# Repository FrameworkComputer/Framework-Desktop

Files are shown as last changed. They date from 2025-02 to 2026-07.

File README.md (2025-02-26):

# Framework-Desktop
Documentation for the Mainboard and printable mechanical parts in the Framework Desktop.

Framework-Desktop-Teardown-2025

## License

Framework Desktop © 2025 by Framework Computer Inc is licensed under CC BY 4.0.
To view a copy of this license, visit https://creativecommons.org/licenses/by/4.0/

## Mainboard

Framework Desktop uses a standard size Mini-ITX Mainboard with standard ATX connectors.

## Case

CAD to enable creation of custom handles and top covers.

## Tiles

CAD to enable creation of custom front tiles.

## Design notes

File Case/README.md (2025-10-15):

# Case

## Case

CAD for the overall case structure.

## Left Panel

CAD for the left panel.

## Top Cover

CAD for the Top Cover part of the Framework Desktop to design alternative versions.

## Handle

OpenSCAD CAD and STL to 3D print a carrying handle for Framework Desktop.

Needs 2x M6 x 12mm (up to 13mm or so) bolts or thumbscrews to attach it.

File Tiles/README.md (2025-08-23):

# Front Cover and Tiles

## License

Front Cover and Tiles © 2025 by Framework Computer Inc is licensed under CC BY 4.0.
To view a copy of this license, visit http://creativecommons.org/licenses/by/4.0/

## Designs

### Front Cover

[fw_desktop_front_cover.stl](fw_desktop_front_cover.stl) is the 3D design file
for the front cover.

The 3D file is mainly intented to help the community develop tiles that are compatible with the official front cover. It does not include magnets or the power button.
If you'd like to attach it to the Framework Desktop you need magnets of size 8.50x5.00x1.10mm. Eight of those are used in the product.

### Tiles

To develop your own tiles we provide 2D and 3D files for the flat printed tiles:

- 2D
    - [FRAMEWORK_DESKTOP_BLANK_TILE.stp](FRAMEWORK_DESKTOP_BLANK_TILE.stp)
- 3D
    - [FRAMEWORK_DESKTOP_BLANK_TILE_V0.pdf](FRAMEWORK_DESKTOP_BLANK_TILE_V0.pdf)
    - [framework_desktop_blank_tile_v0_1.dxf](framework_desktop_blank_tile_v0_1.dxf)
    - [framework_desktop_blank_tile_v0_2.dxf](framework_desktop_blank_tile_v0_2.dxf)
    - [framework_desktop_blank_tile_v0_3.dxf](framework_desktop_blank_tile_v0_3.dxf)

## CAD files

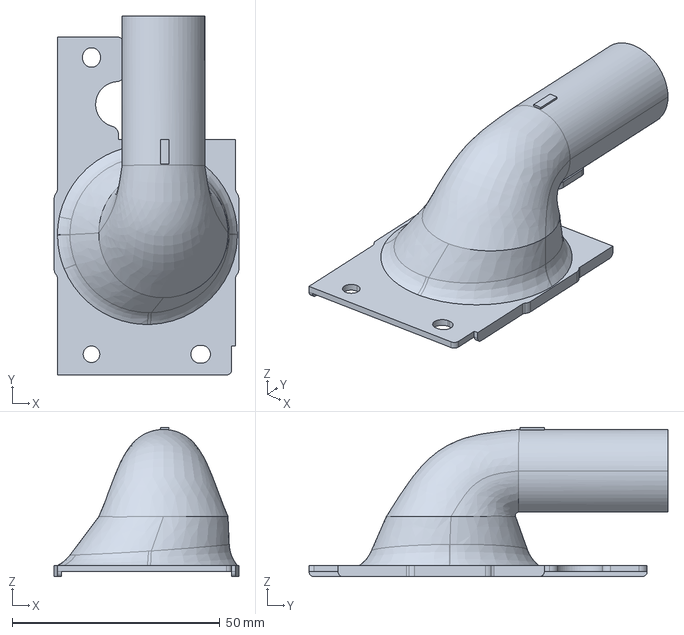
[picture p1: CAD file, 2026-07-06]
Case/framework_desktop_psu_duct.stp
44.5 x 86.5 x 36.0 mm

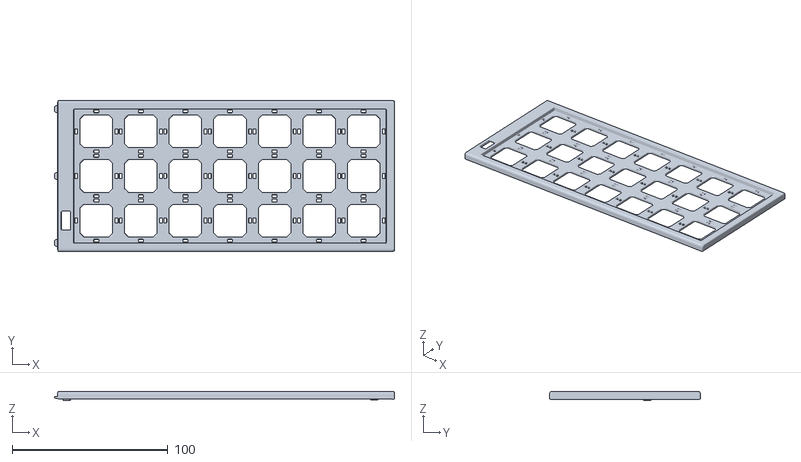
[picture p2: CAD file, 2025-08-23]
Tiles/fw_desktop_front_cover.stl
218.2 x 96.8 x 6.00

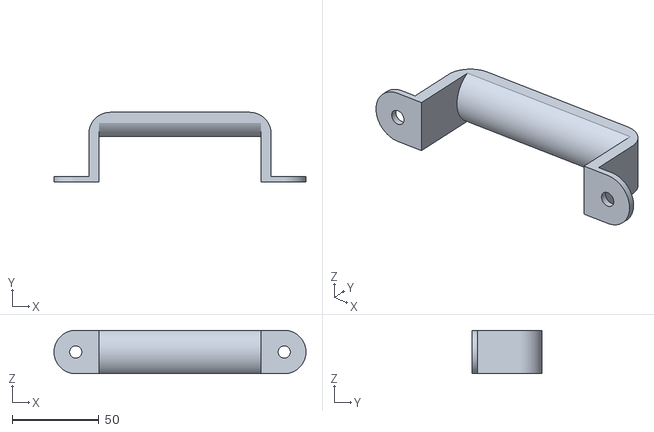
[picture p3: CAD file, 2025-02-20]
Case/handle.stl
145.0 x 40.0 x 25.0

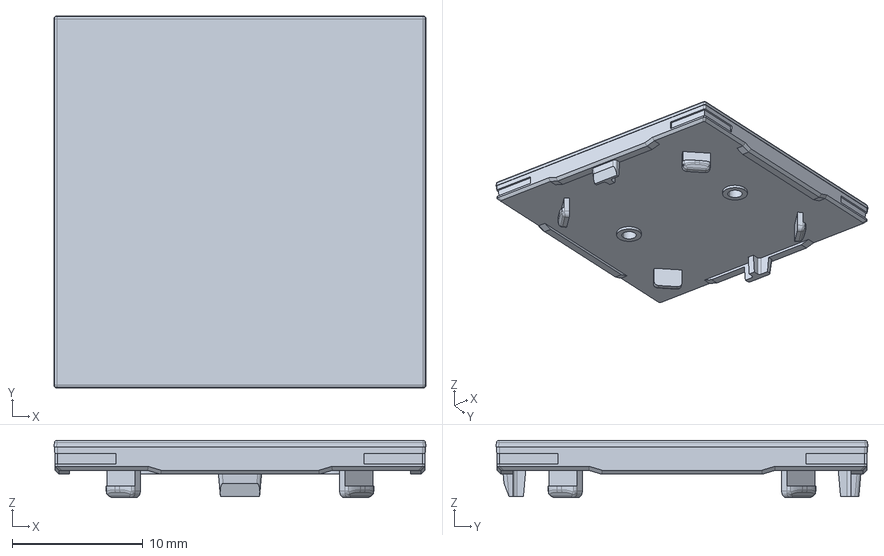
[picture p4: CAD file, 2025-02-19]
Tiles/FRAMEWORK_DESKTOP_BLANK_TILE.stp
28.5 x 28.5 x 4.40 mm

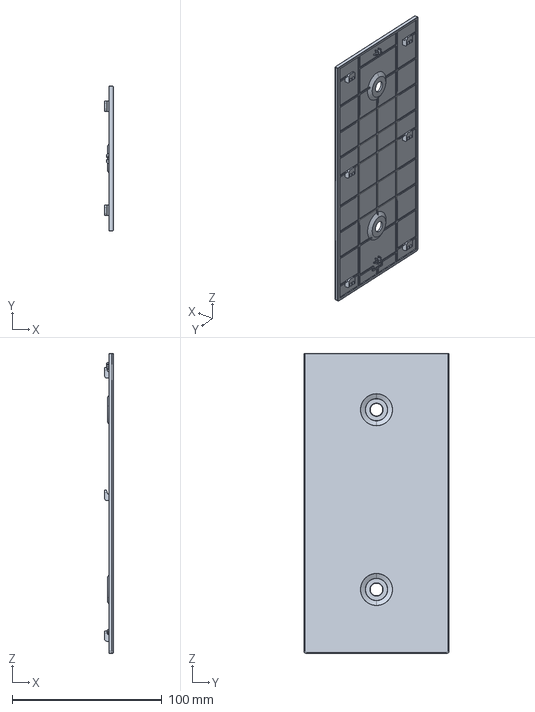
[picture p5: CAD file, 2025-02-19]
Case/FRAMEWORK_DESKTOP_TOP_COVER_V0.stp
5.85 x 96.8 x 200.3 mm

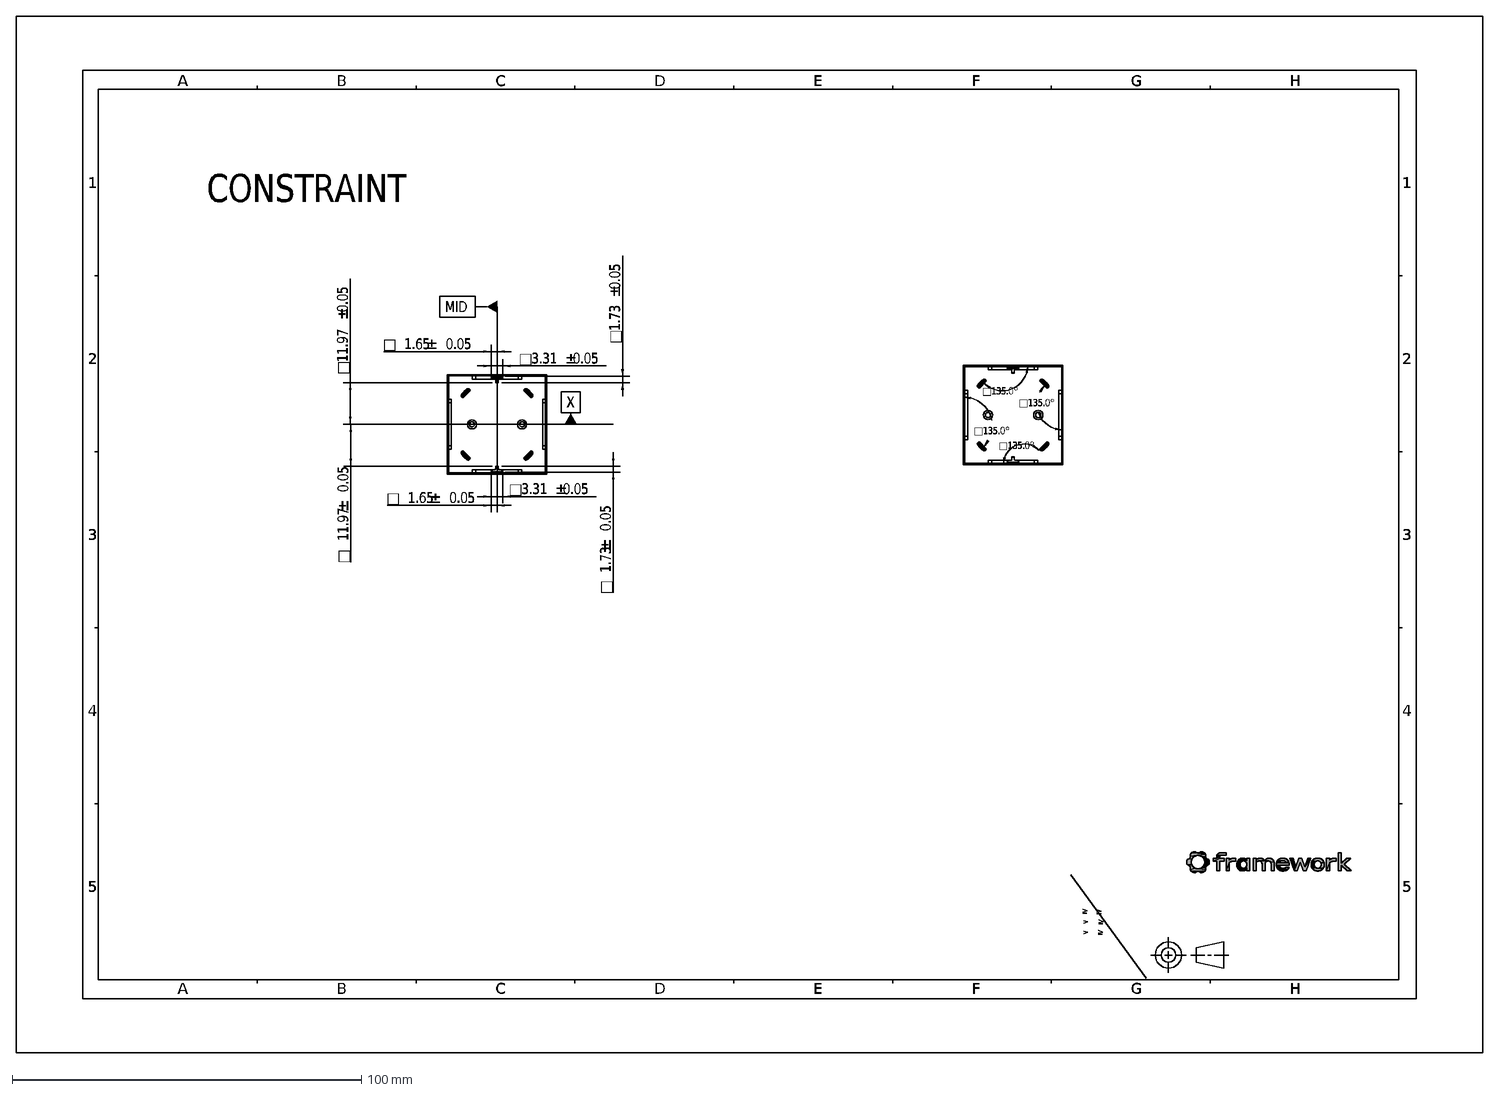
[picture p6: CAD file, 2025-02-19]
Tiles/framework_desktop_blank_tile_v0_3.dxf
A
B
5
4
3
2
1
C
D
E
F
G
H
MID
X
3.31
0.05
1.65
1.73
11.97
CONSTRAINT

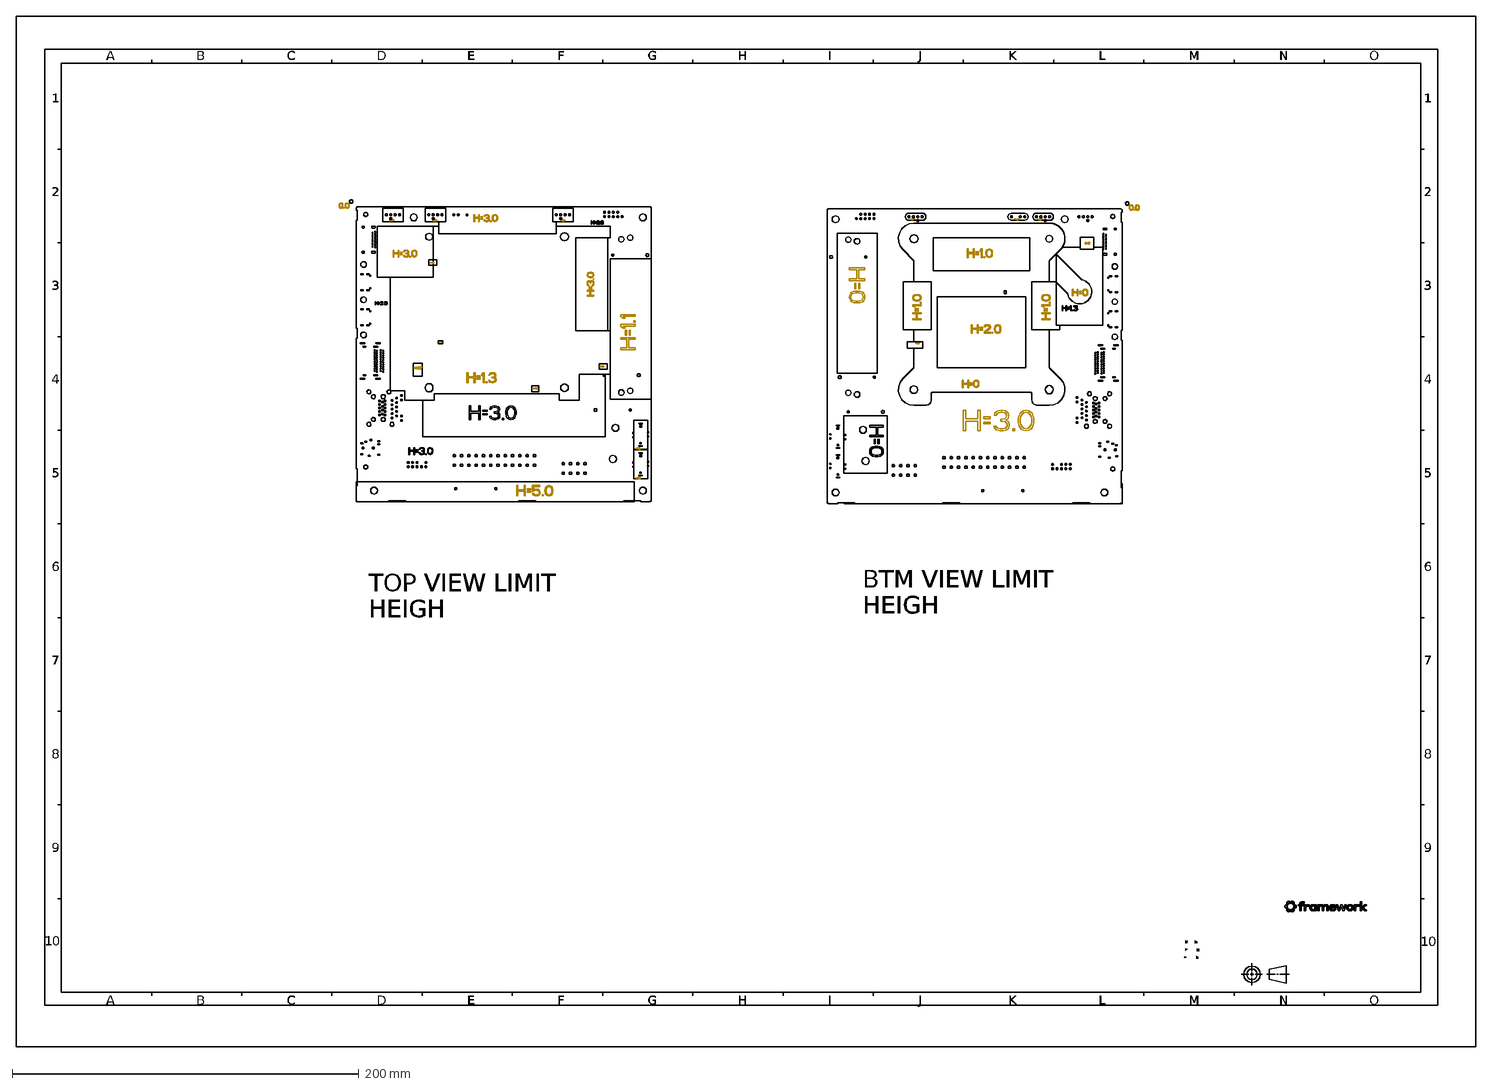
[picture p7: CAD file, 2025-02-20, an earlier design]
Mainboard/framework_desktop_main_pcb_v0_3.dxf
A
10
B
C
9
8
D
E
F
G
6
7
5
4
3
2
1
H
I
J
K
L
M
N
O
TOP VIEW LIMIT HEIGH
BTM VIEW LIMIT HEIGH

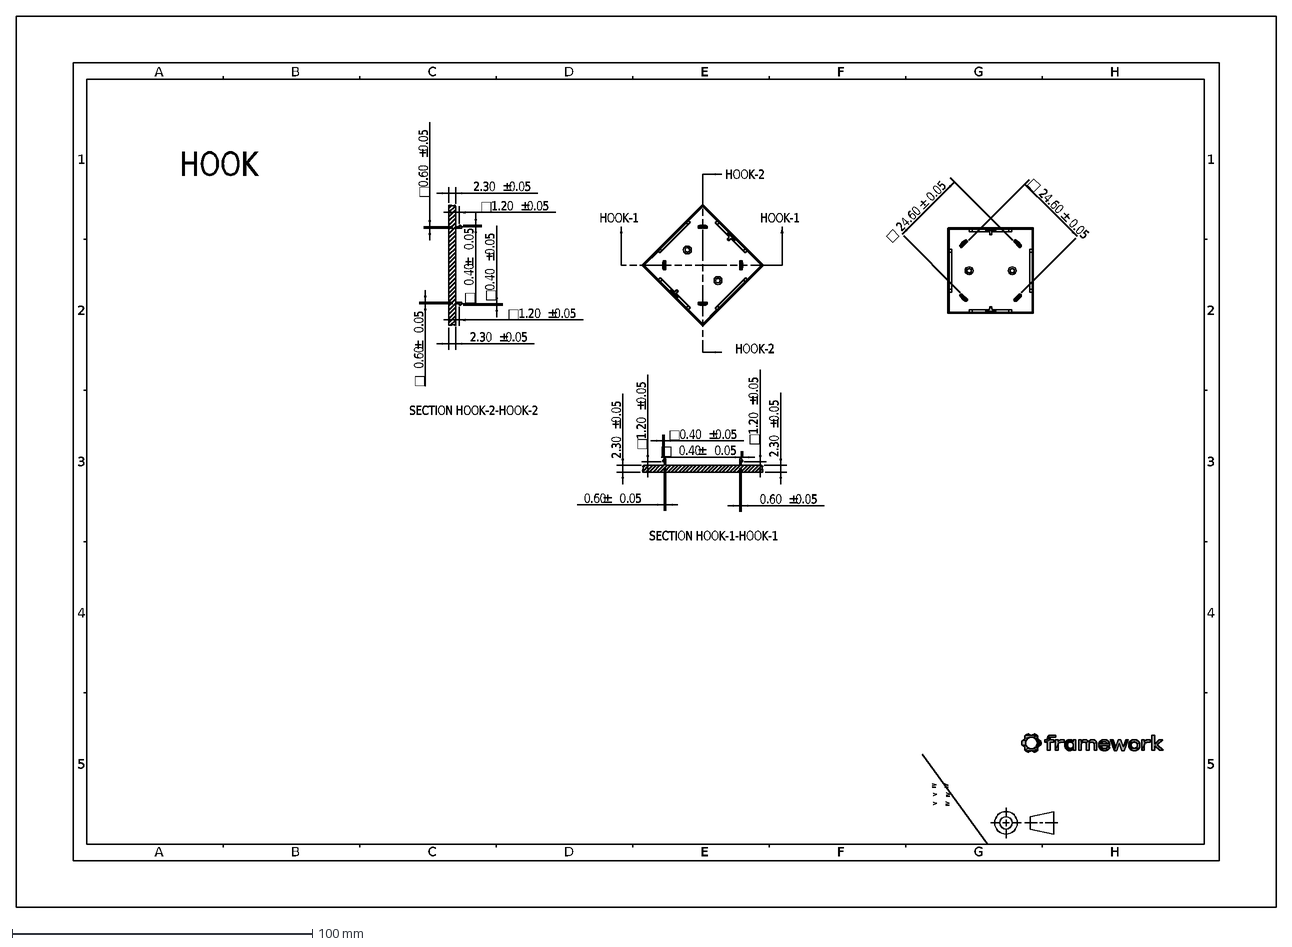
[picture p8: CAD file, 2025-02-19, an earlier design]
Tiles/framework_desktop_blank_tile_v0_2.dxf
A
B
5
4
3
2
1
C
D
E
F
G
H
HOOK-1
HOOK-2
1.20
0.05
0.40
2.30
0.60
24.60
HOOK
SECTION HOOK-1-HOOK-1
SECTION HOOK-2-HOOK-2

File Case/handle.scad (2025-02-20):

// Framework Desktop Handle
//  An OpenSCAD implementation of a carrying handle for the Framework Desktop
//
//  Print it laying on its side for layer strength.
//  Needs 2x M6 x 12mm bolts or thumbscrews to attach to the system.
//
// Framework Desktop Handle © 2025 Framework Computer Inc
// is licensed under Attribution 4.0 International. 
// To view a copy of this license, visit http://creativecommons.org/licenses/by/4.0/

include <MCAD/boxes.scad>;

// Matching the bolt spacing on the Top Cover
hole_to_hole = 120;

// Handle height
height = 40;
// Handle width
width = 25;
// Tradeoff between more thumbscrew clearance vs hand space
hole_offset = 15;
thickness = width/2;
// 3mm is enough strength when using typical filament
base_thickness = 3;
r = thickness;
// Bolt hole diameter
m6_r = 6/2 + 0.5;

$fn = 128;

difference() {
    union() {
        intersection() {
            // Rounding the overall shape of the handle by starting with a rounded cube
            translate([hole_offset/2, -r, 0]) roundedCube([hole_to_hole - hole_offset, height + r, width], r, true);
            // Rounding each section of the handle by making each a cylinder
            union() {
                // The two vertical pieces
                translate([hole_offset/2, 0, width]) rotate([-90, 0, 0]) cube([base_thickness*2, width, height]);
                translate([hole_to_hole - hole_offset/2 - base_thickness*2, 0, width]) rotate([-90, 0, 0]) cube([base_thickness*2, width, height]);
                // The horizontal piece
                translate([hole_offset/2, height, width/2]) rotate([0, 90, 0]) cylinder(h = hole_to_hole - hole_offset, r = width/2 + base_thickness/2); 
            }
        }
        
        // The flat parts that the bolts go through
        mount_length = width + hole_offset/2;
        translate([-width/2, 0, width]) rotate([-90, 0, 0]) roundedCube([mount_length, width, base_thickness], width/2, true);
        translate([hole_to_hole - width + (width - hole_offset)/2, 0, width]) rotate([-90, 0, 0]) roundedCube([mount_length, width, base_thickness], width/2, true);
    }
    
    // Cutting out the hand area on the base
    translate([hole_offset/2 + base_thickness*2, 0, 0]) cube([hole_to_hole - hole_offset - base_thickness*4, height - r - base_thickness/2, width]);
    
    // The bolt holes
    translate([0, 0, width/2]) rotate([-90, 0, 0]) cylinder(h = height, r = m6_r);
    translate([hole_to_hole, 0, width/2]) rotate([-90, 0, 0]) cylinder(h = height, r = m6_r);    
}

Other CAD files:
Mainboard/framework_desktop_main_pcb_v0_4.dxf
Case/framework_desktop_topcover_v0_2.dxf
Mainboard/framework_desktop_main_pcb_v0_2.dxf
Tiles/framework_desktop_blank_tile_v0_1.dxf
Case/framework_desktop_topcover_v0_1.dxf

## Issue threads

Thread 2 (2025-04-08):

Add cooler and fan shroud to the 3d model of the motherboard

KonradStuewe, 2025-04-08:
Is there any way that you can publish the 3D model of the cooler and the fan shroud?
I'm trying to make my own case and knowing where exactly the fan sits in relation to the rest of the board, would really help with that.

Djip007, 2025-05-23:
All size is here https://github.com/FrameworkComputer/Framework-Desktop/blob/main/Mainboard/FRAMEWORK_DESKTOP_MAIN_PCB_V0.pdf

but yes not in stl.

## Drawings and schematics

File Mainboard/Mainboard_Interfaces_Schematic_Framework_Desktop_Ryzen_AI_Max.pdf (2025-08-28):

# Block Diagram

# APU

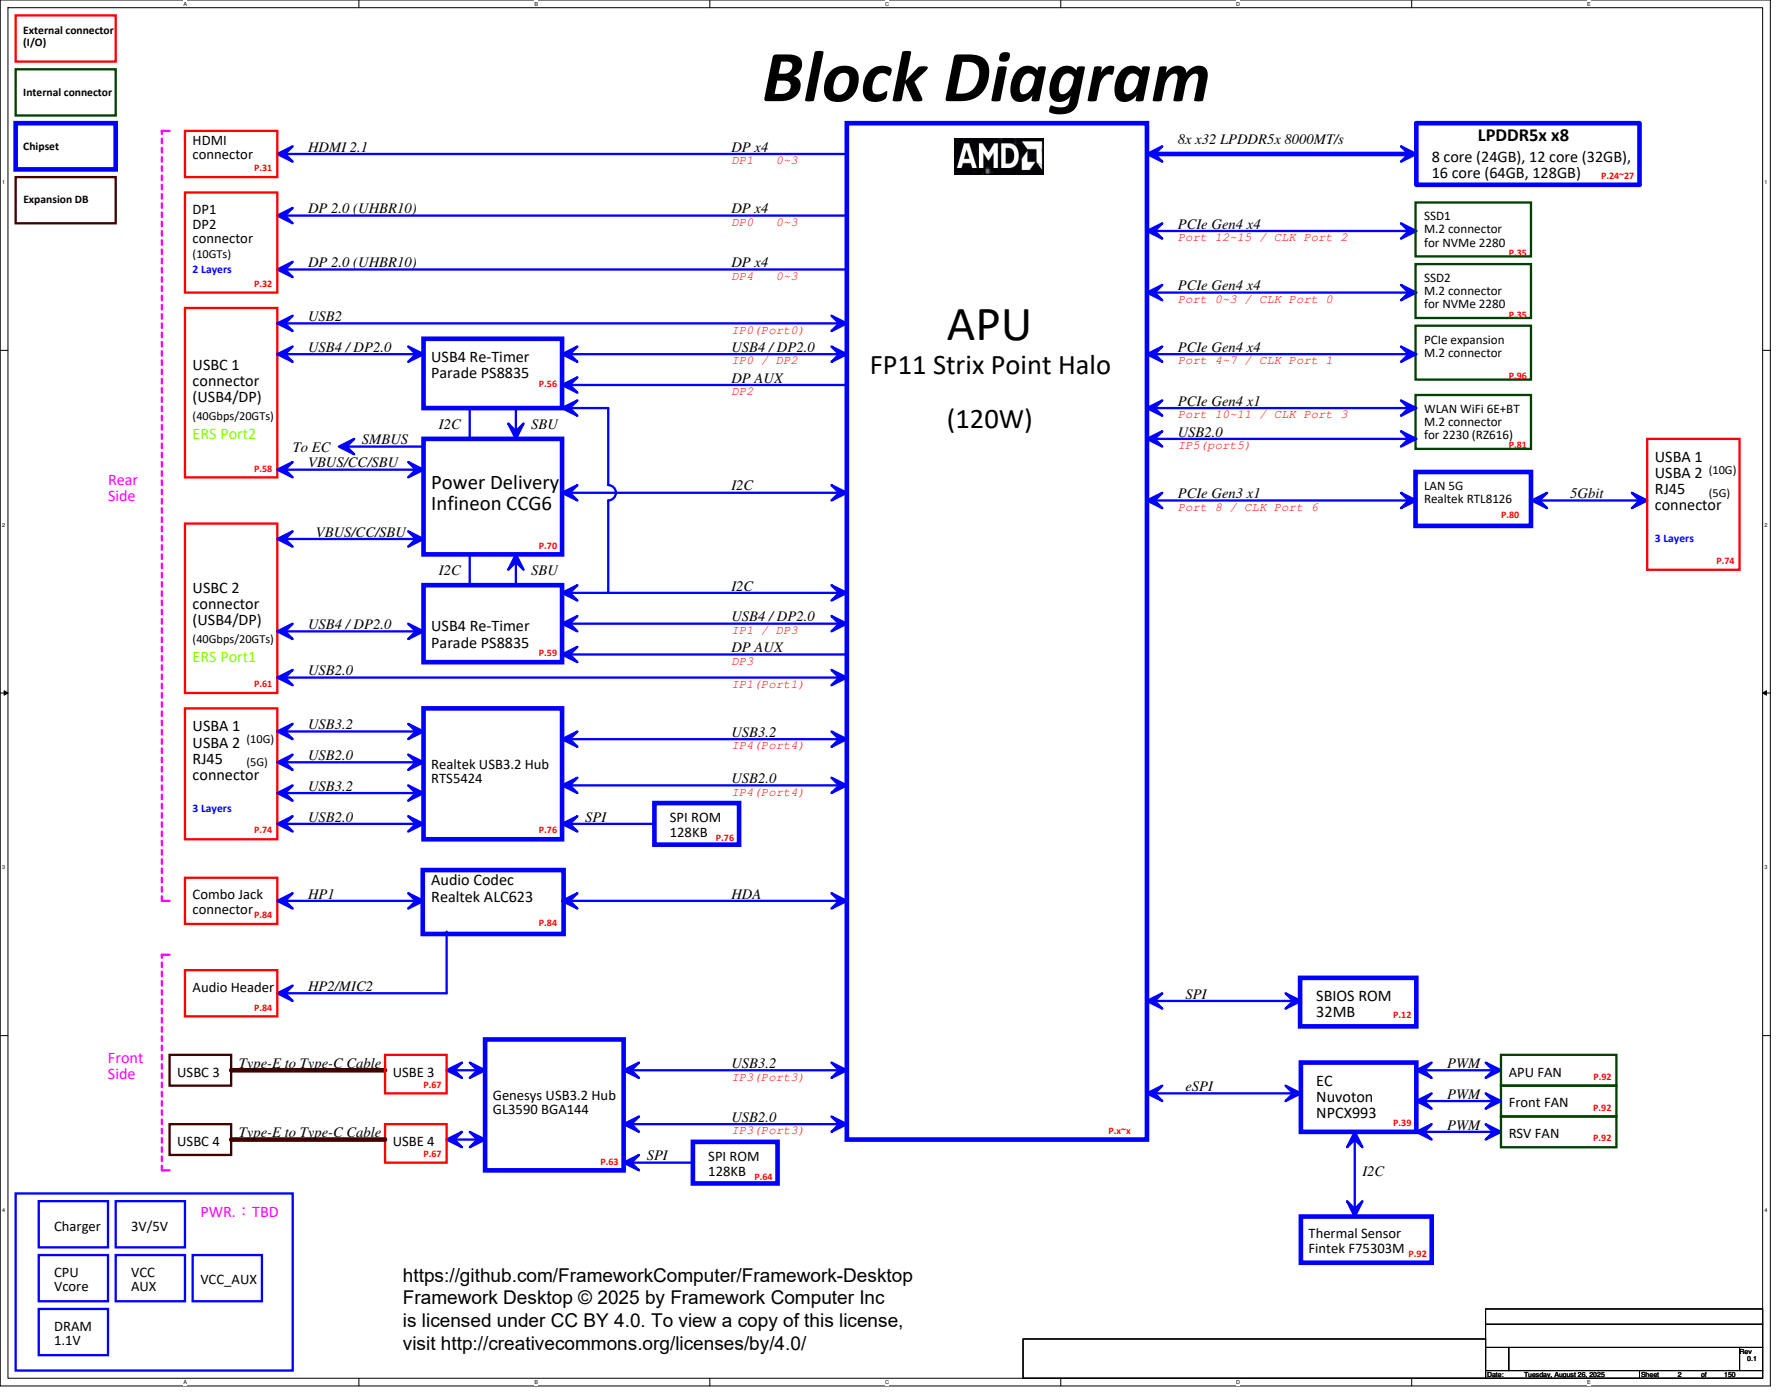
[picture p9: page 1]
SBIOS ROM 32MB; VCC AUX; Charger; CPU; Vcore; VCC_AUX; DRAM 1.1V; USBC 1 connector (USB4/DP); Power Delivery Infineon CCG6; LPDDR5x x8; 8 core (24GB), 12 core (32GB), 16 core (64GB, 128GB); 8x x32 LPDDR5x 8000MT/s; USB4 / DP2.0; HDMI 2.1; HDMI; connector; DP 2.0 (UHBR10); USBC 2 connector (USB4/DP); Internal connector; External connector (I/O); Chipset; IP4(Port4); SSD2 M.2 connector for NVMe 2280; PCIe expansion M.2 connector; SSD1 M.2 connector for NVMe 2280; PCIe Gen3 x1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

PCIe Gen4 x4
Port 12~15 / CLK Port 2

Port 0~3 / CLK Port 0

Port 4~7 / CLK Port 1

FP11 Strix Point Halo

WLAN WiFi 6E+BT
M.2 connector
for 2230 (RZ616)

VBUS/CC/SBU

Port 8 / CLK Port 6

Type-E to Type-C Cable

Front FAN PWM

RSV FAN PWM

https://github.com/FrameworkComputer/Framework-Desktop
Framework Desktop © 2025 by Framework Computer Inc
is licensed under CC BY 4.0. To view a copy of this license,
visit http://creativecommons.org/licenses/by/4.0/

## Main Function:

# S0ix Off

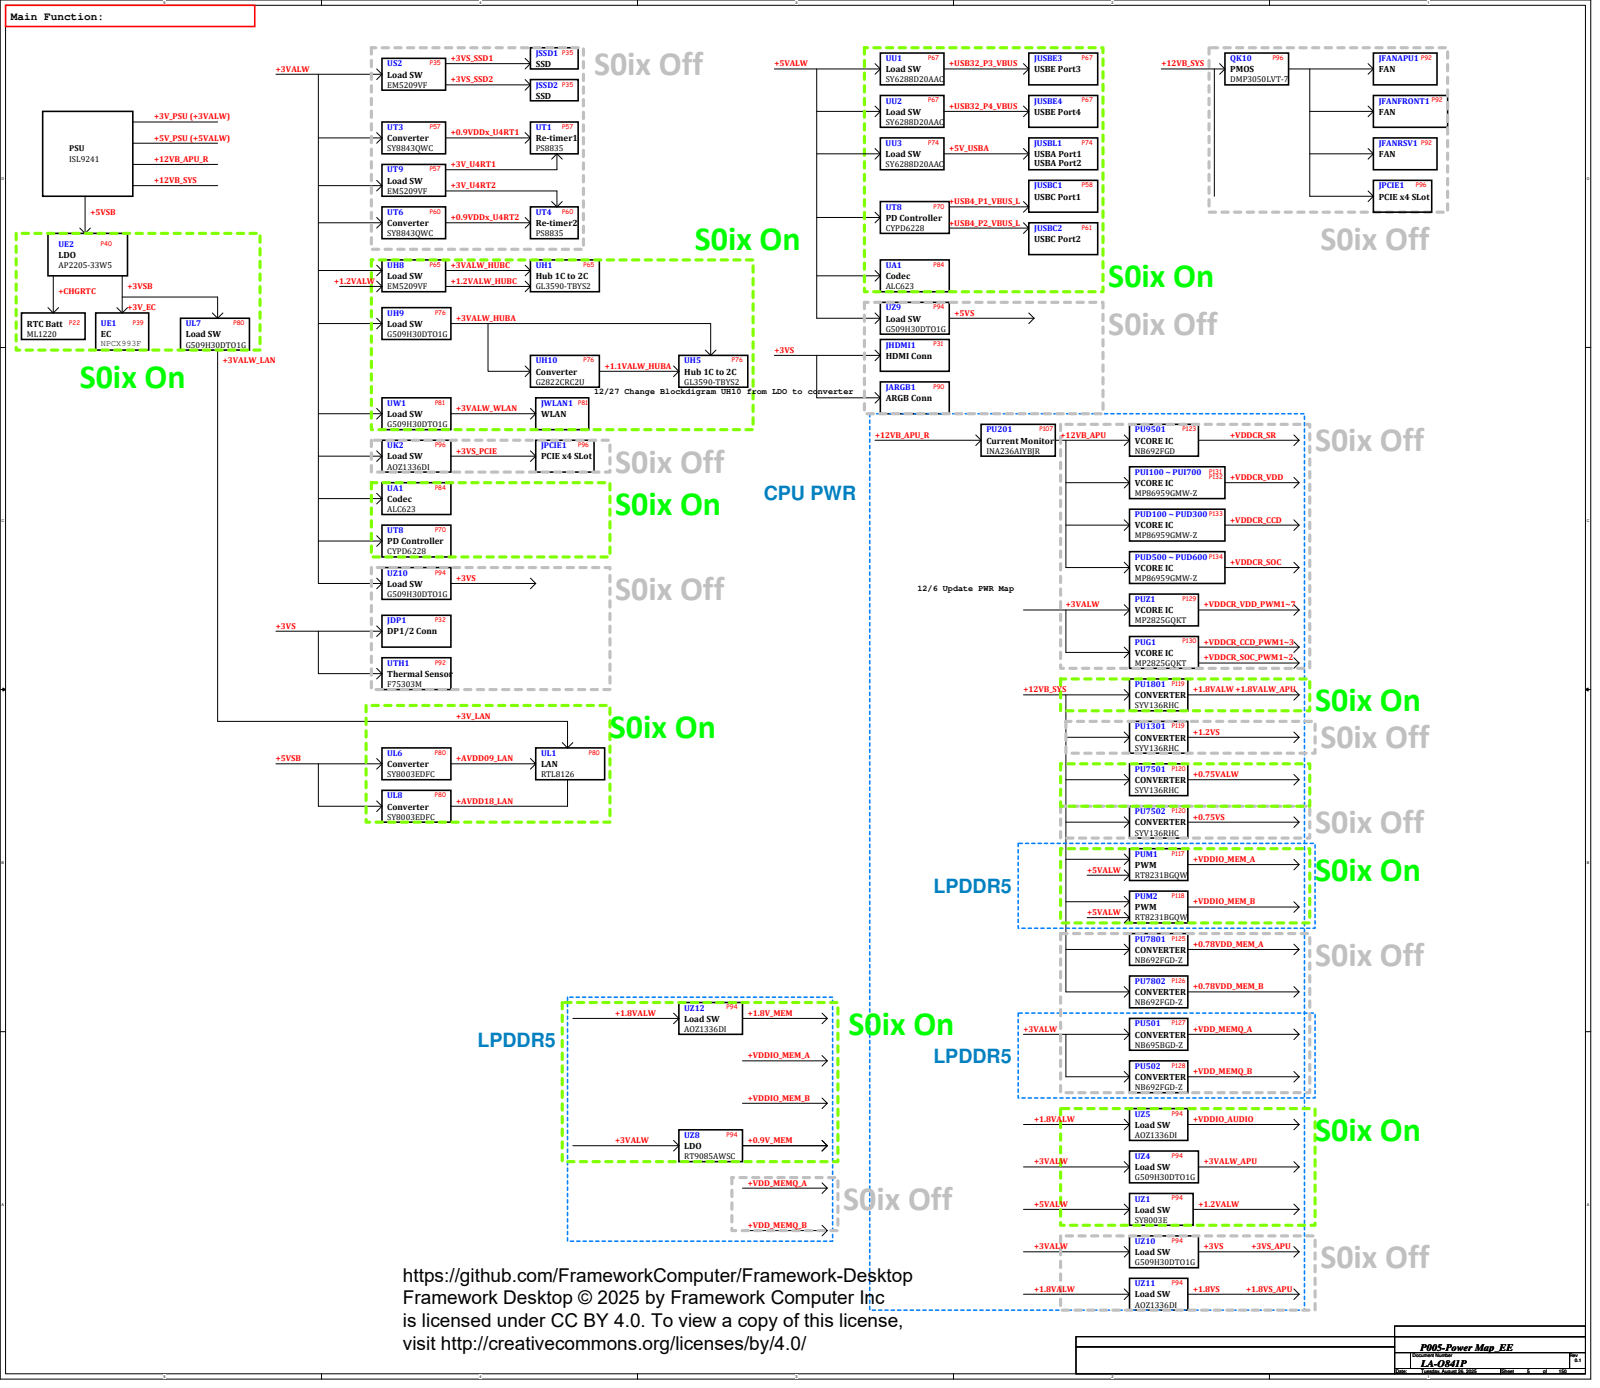
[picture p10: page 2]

12/27 Change Blockdigram UH10 from LDO to converter

https://github.com/FrameworkComputer/Framework-Desktop
Framework Desktop © 2025 by Framework Computer Inc

# HDMI_CEC

## 8/5 change to +3VL_EC

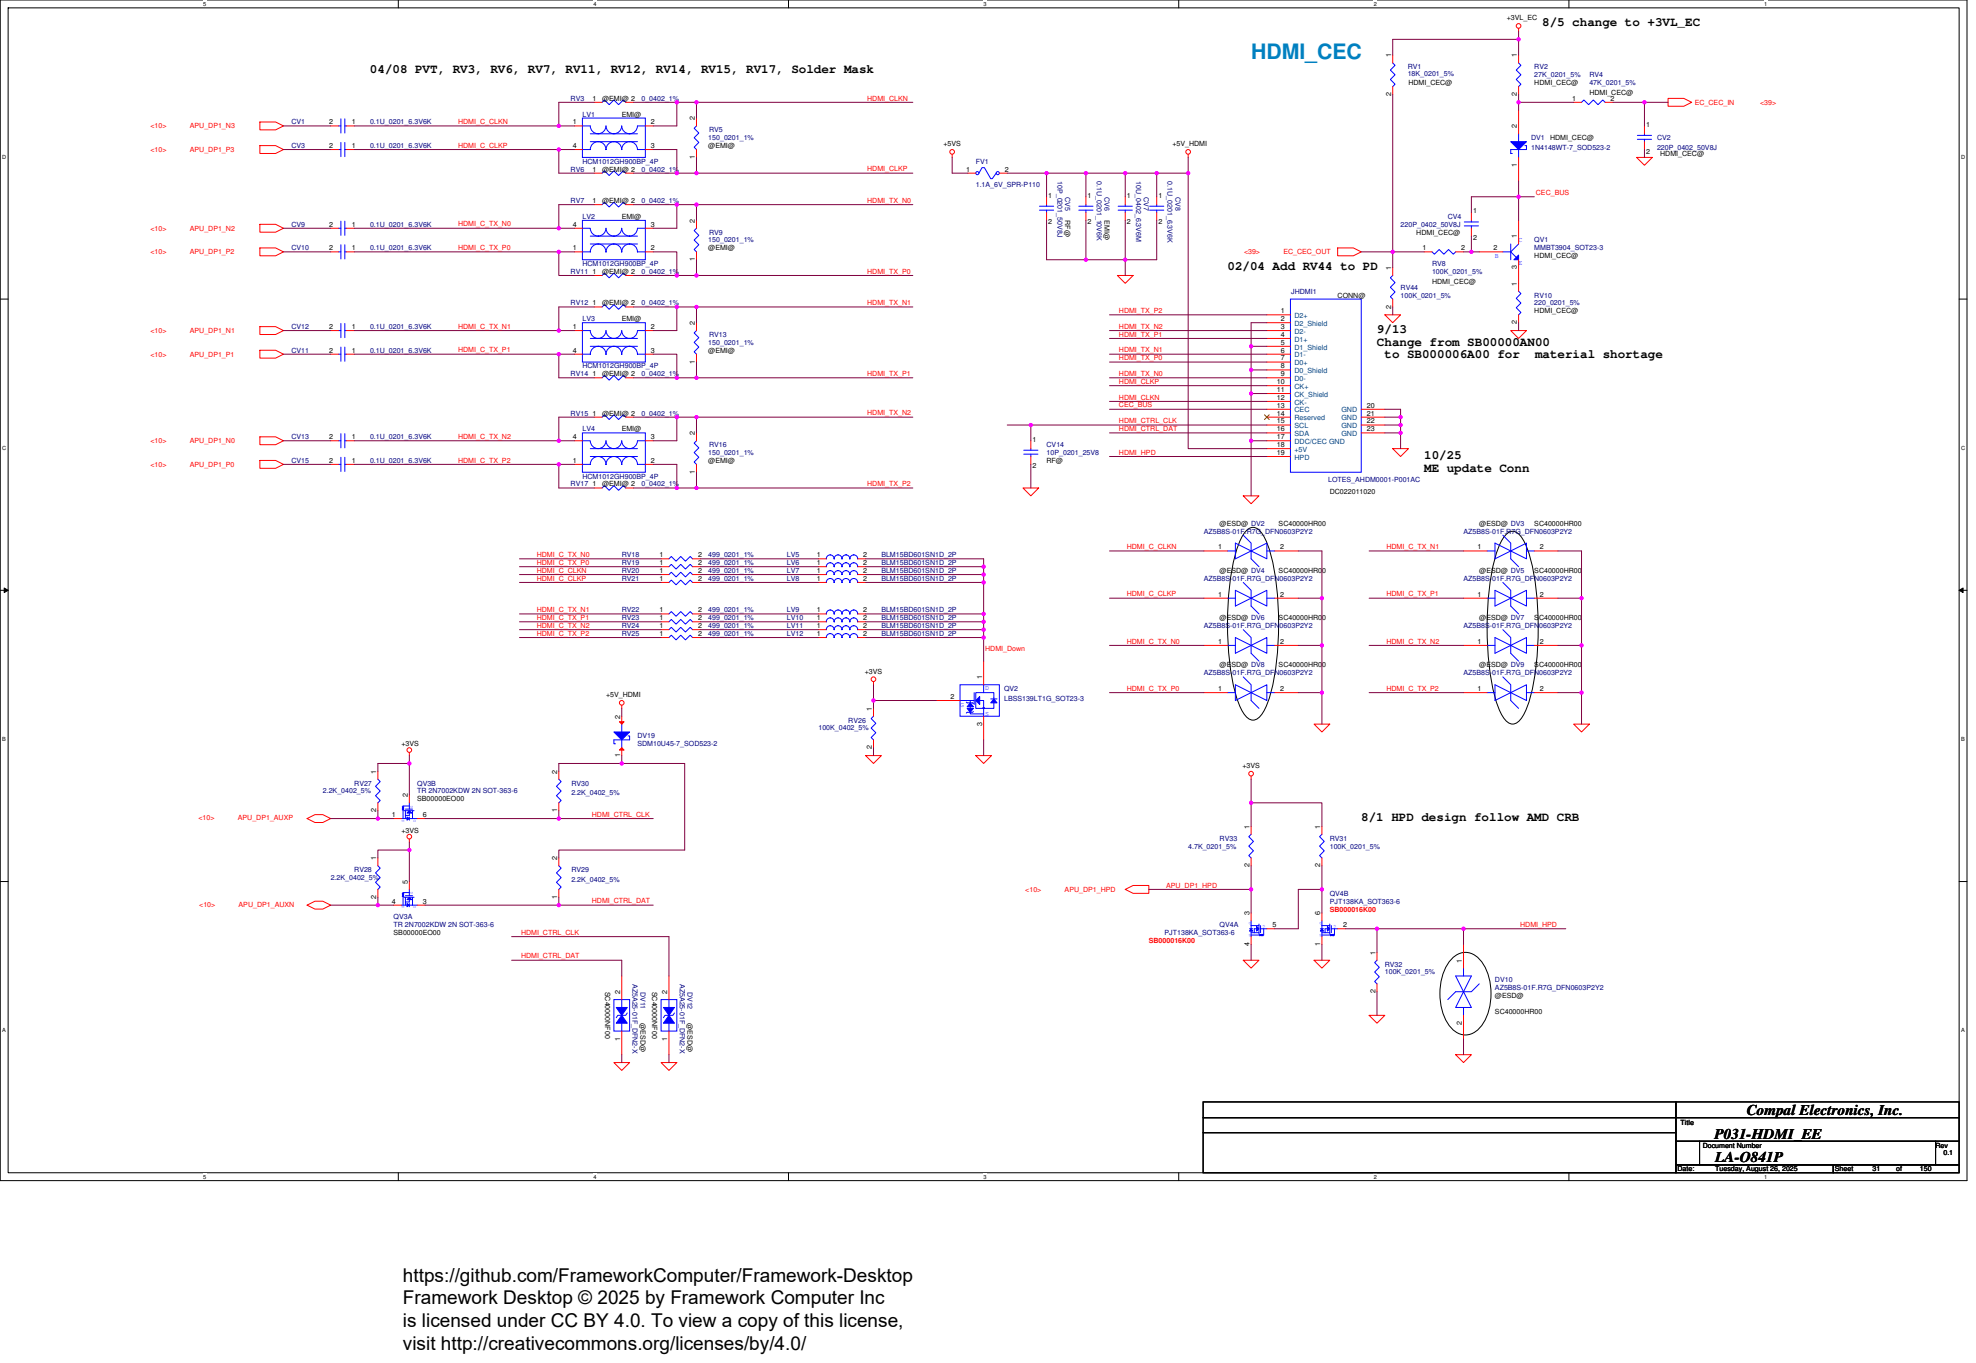
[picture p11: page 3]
9/13 Change from SB00000AN00; to SB000006A00 for; material shortage; APU_DP1_P2; APU_DP1_N2; APU_DP1_N1; APU_DP1_P1; APU_DP1_N0; APU_DP1_P0; APU_DP1_N3; APU_DP1_P3; APU_DP1_AUXP; APU_DP1_AUXN; EC_CEC_IN; EC_CEC_OUT; APU_DP1_HPD; +5V_HDMI; Title; Document Number; Rev; Date:; Sheet; Tuesday, August 26, 2025; RV5 150_0201_1% @EMI@; PJT138KA_SOT363-6 SB000016K00; DV3 AZ5B8S-01F.R7G_DFN0603P2Y2; @ESD@; BLM15BD601SN1D_2P; RV2 27K_0201_5% HDMI_CEC@; HCM1012GH900BP_4P; EMI@ 1 2; 1 @EMI@ 2 0_0402_1%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

04/08 PVT, RV3, RV6, RV7, RV11, RV12, RV14, RV15, RV17, Solder Mask

02/04 Add RV44 to PD

ME update Conn

8/1 HPD design follow AMD CRB

Compal Electronics, Inc.
P031-HDMI_EE

https://github.com/FrameworkComputer/Framework-Desktop
Framework Desktop © 2025 by Framework Computer Inc

# Main Func = DP1/2

8/1 HPD design follow AMD CRB | 8/1 HPD design follow AMD CRB

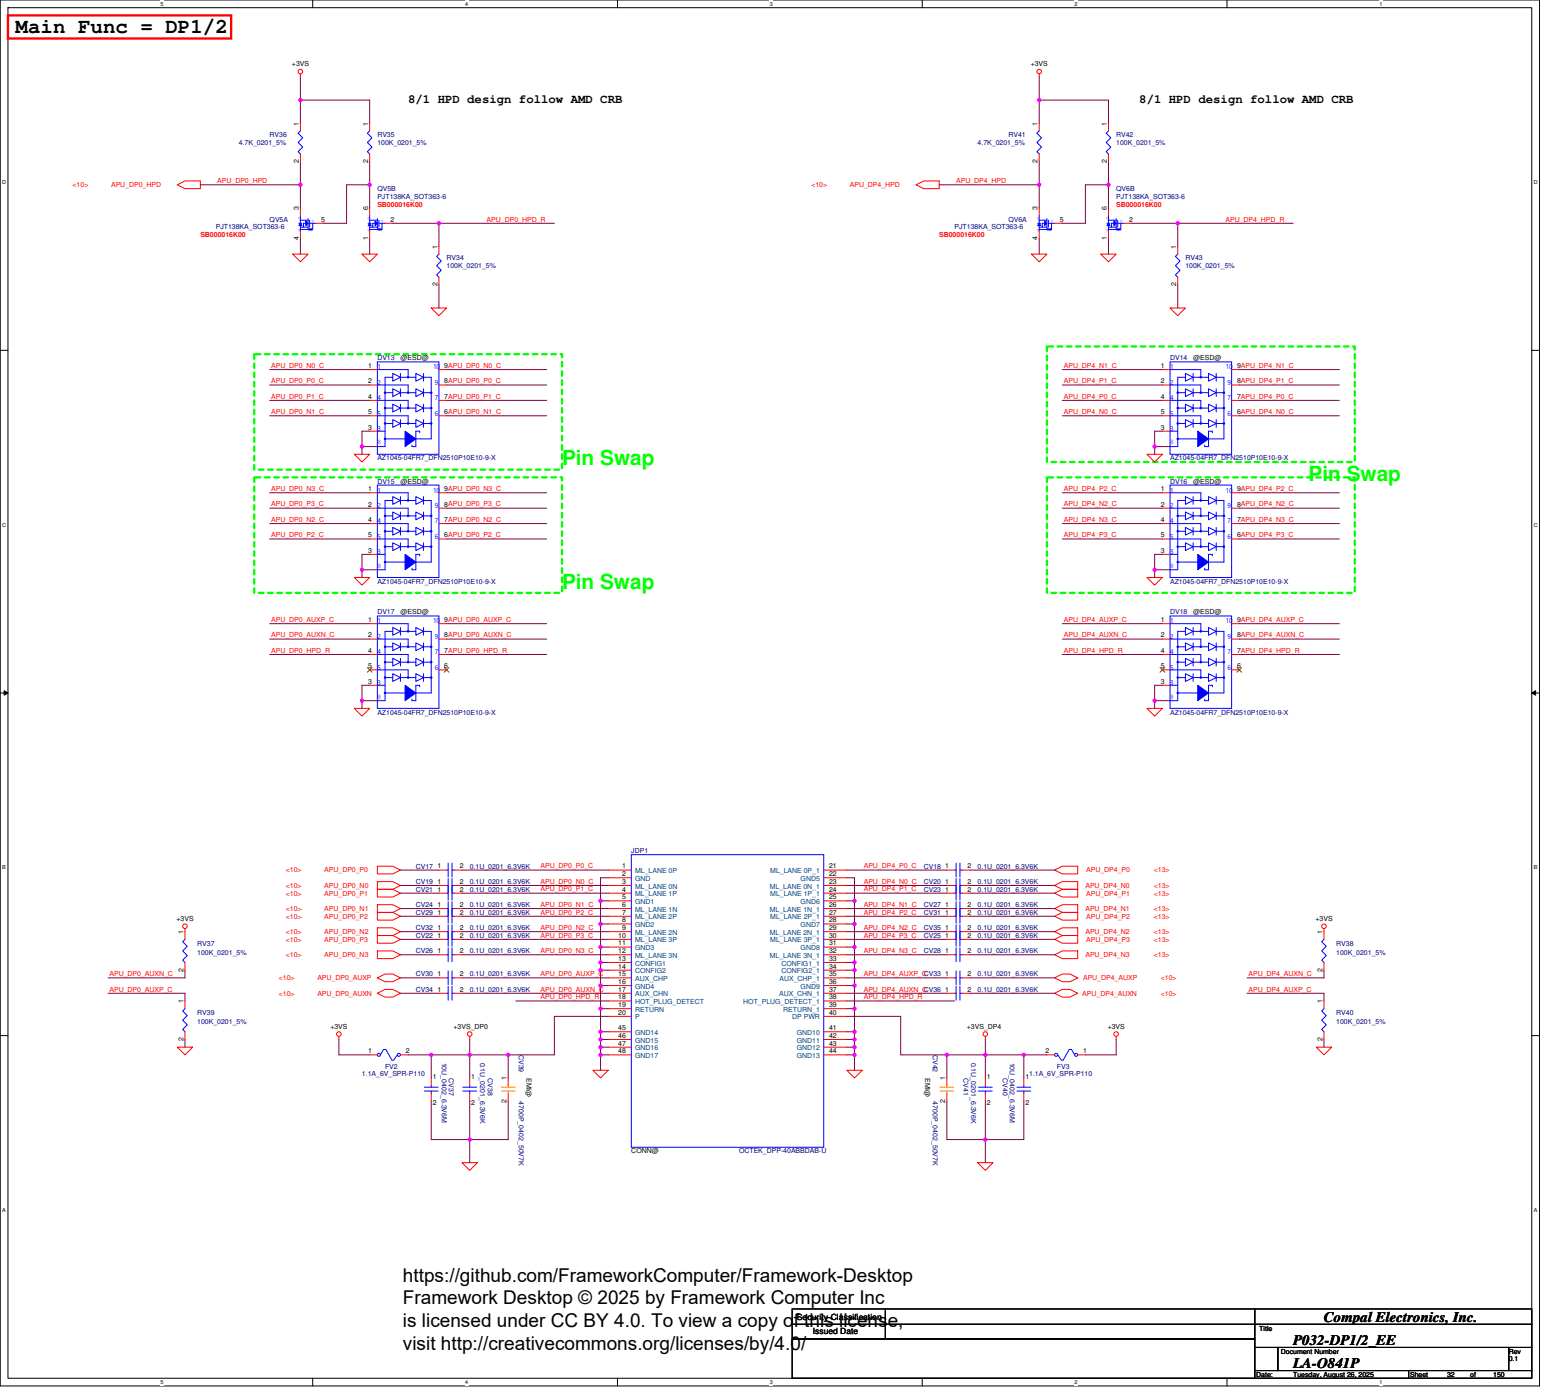
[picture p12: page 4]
Pin Swap; APU_DP0_P0; APU_DP0_N0; APU_DP0_P1; APU_DP0_N1; APU_DP0_P2; APU_DP0_N2; APU_DP0_P3; APU_DP0_N3; APU_DP0_AUXP; APU_DP0_AUXN; APU_DP4_P0; APU_DP4_N0; APU_DP4_P1; APU_DP4_N1; APU_DP4_P2; APU_DP4_N2; APU_DP4_P3; APU_DP4_N3; APU_DP4_AUXP; APU_DP4_AUXN; APU_DP0_HPD; APU_DP4_HPD; Title; Security Classification; Issued Date; Tuesday, August 26, 2025; EMI@; AZ1045-04FR7_DFN2510P10E10-9-X; @ESD@; QV5B PJT138KA_SOT363-6 SB000016K00 6; QV6B PJT138KA_SOT363-6 SB000016K00 6; FV2 1.1A_6V_SPR-P110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

https://github.com/FrameworkComputer/Framework-Desktop
Framework Desktop © 2025 by Framework Computer Inc

Compal Electronics, Inc.

## CLOSE TO PIN 12,14,16,18

## CLOSE TO PIN 2,4

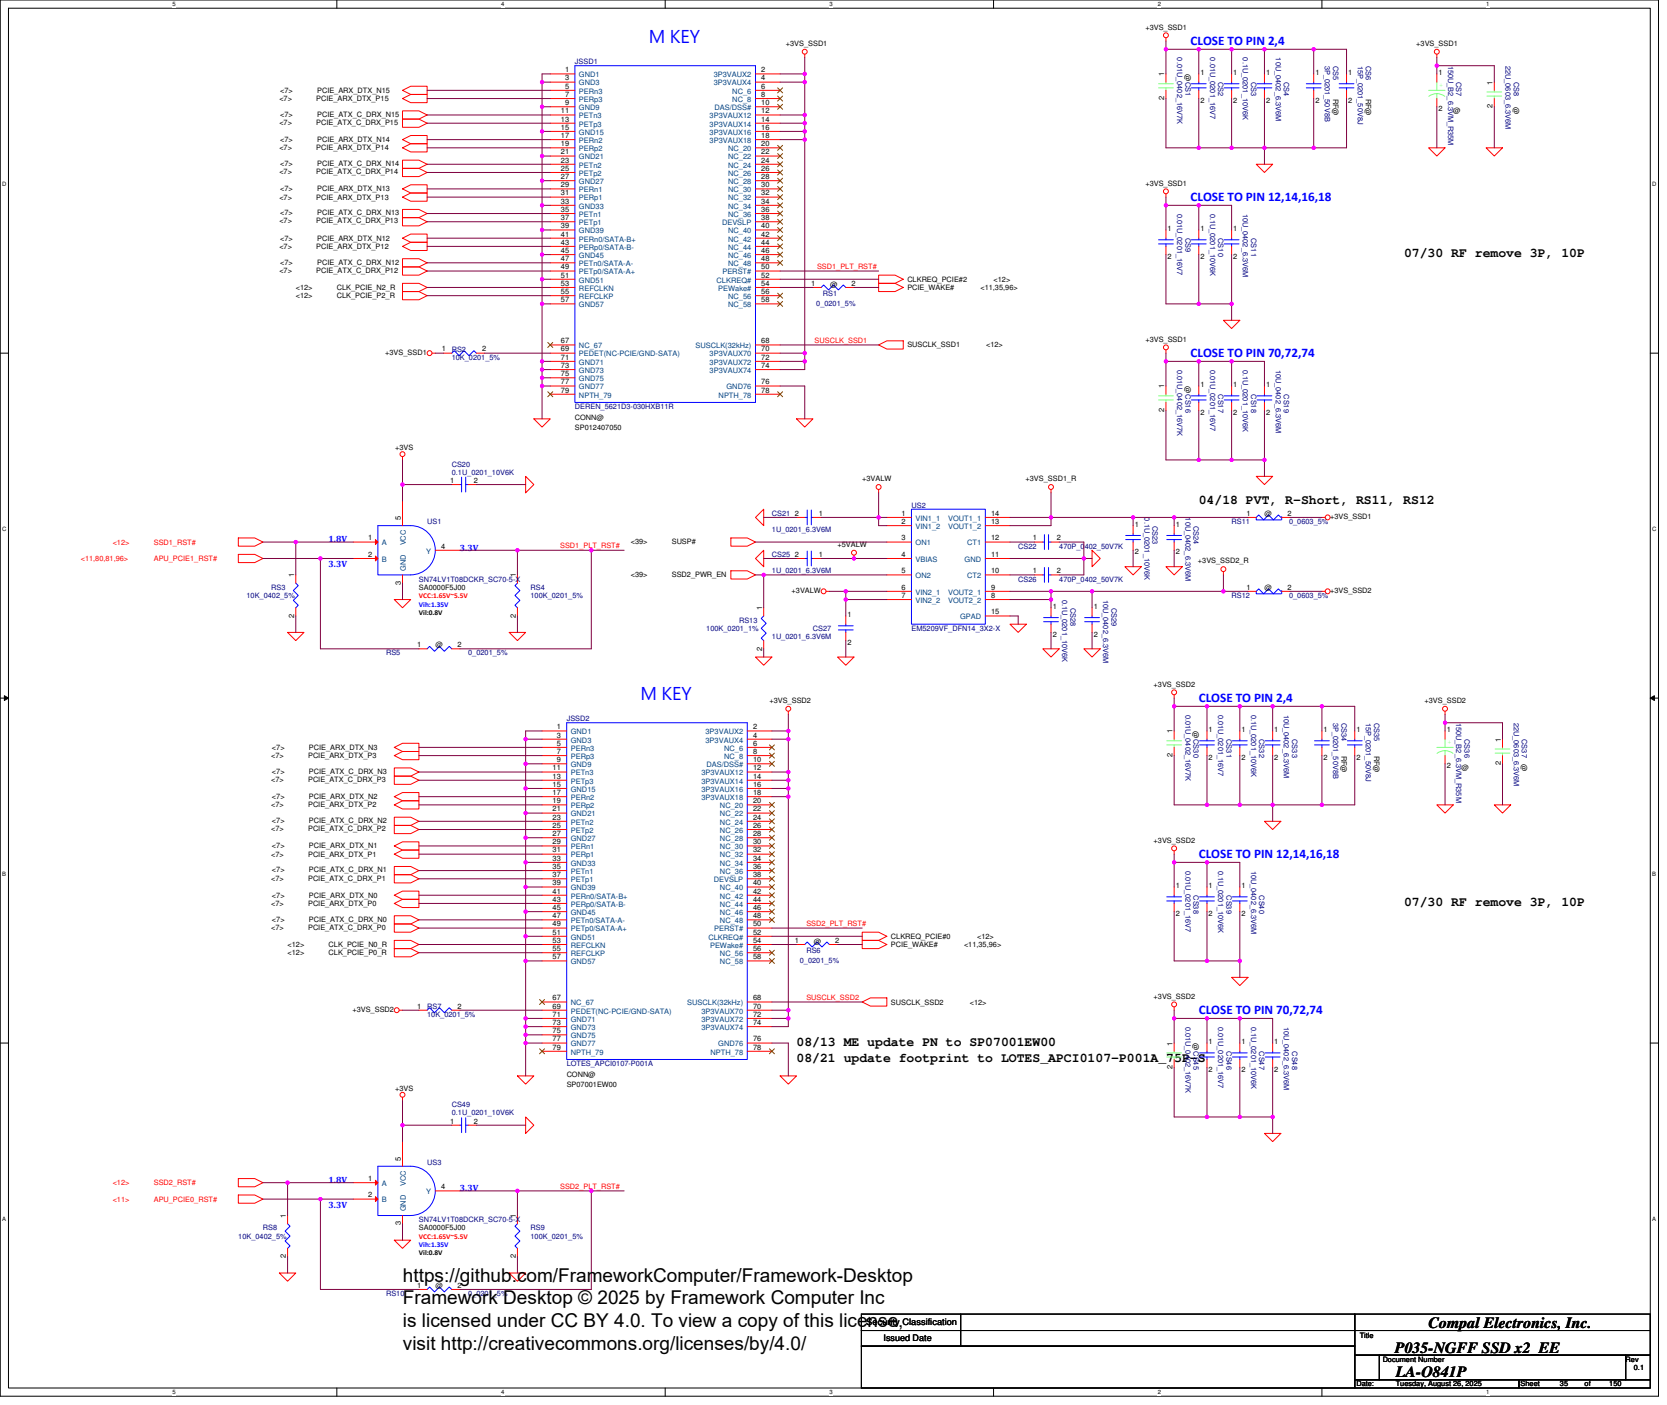
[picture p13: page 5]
M KEY; Vil:0.8V; Vih:1.35V; VCC:1.65V~5.5V; 07/30 RF remove 3P, 10P; 04/18 PVT, R-Short, RS11, RS12; SUSCLK_SSD2; APU_PCIE1_RST#; SSD1_RST#; SSD2_RST#; APU_PCIE0_RST#; SSD2_PWR_EN; CLKREQ_PCIE#0; CLKREQ_PCIE#2; SUSCLK_SSD1; SUSP#; CLK_PCIE_P2_R; CLK_PCIE_N2_R; CLK_PCIE_N0_R; CLK_PCIE_P0_R; PCIE_ARX_DTX_N15; PCIE_ARX_DTX_P15; PCIE_ATX_C_DRX_N15; PCIE_ATX_C_DRX_P15; PCIE_ARX_DTX_N14; PCIE_ARX_DTX_P14; PCIE_ATX_C_DRX_N14; PCIE_ATX_C_DRX_P14; PCIE_ARX_DTX_N13; PCIE_ARX_DTX_P13; PCIE_ATX_C_DRX_N13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

CLOSE TO PIN 70,72,74

CLOSE TO PIN 2,4

CLOSE TO PIN 12,14,16,18

08/13 ME update PN to SP07001EW00
08/21 update footprint to LOTES_APCI0107-P001A_75P-S

SN74LV1T08DCKR_SC70-5-X
VCC:1.65V~5.5V
Vih:1.35V
Vil:0.8V
https://github.com/FrameworkComputer/Framework-Desktop
Framework Desktop © 2025 by Framework Computer Inc

# Main Function: USBC1
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

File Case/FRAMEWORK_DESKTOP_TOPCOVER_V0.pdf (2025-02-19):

2

1

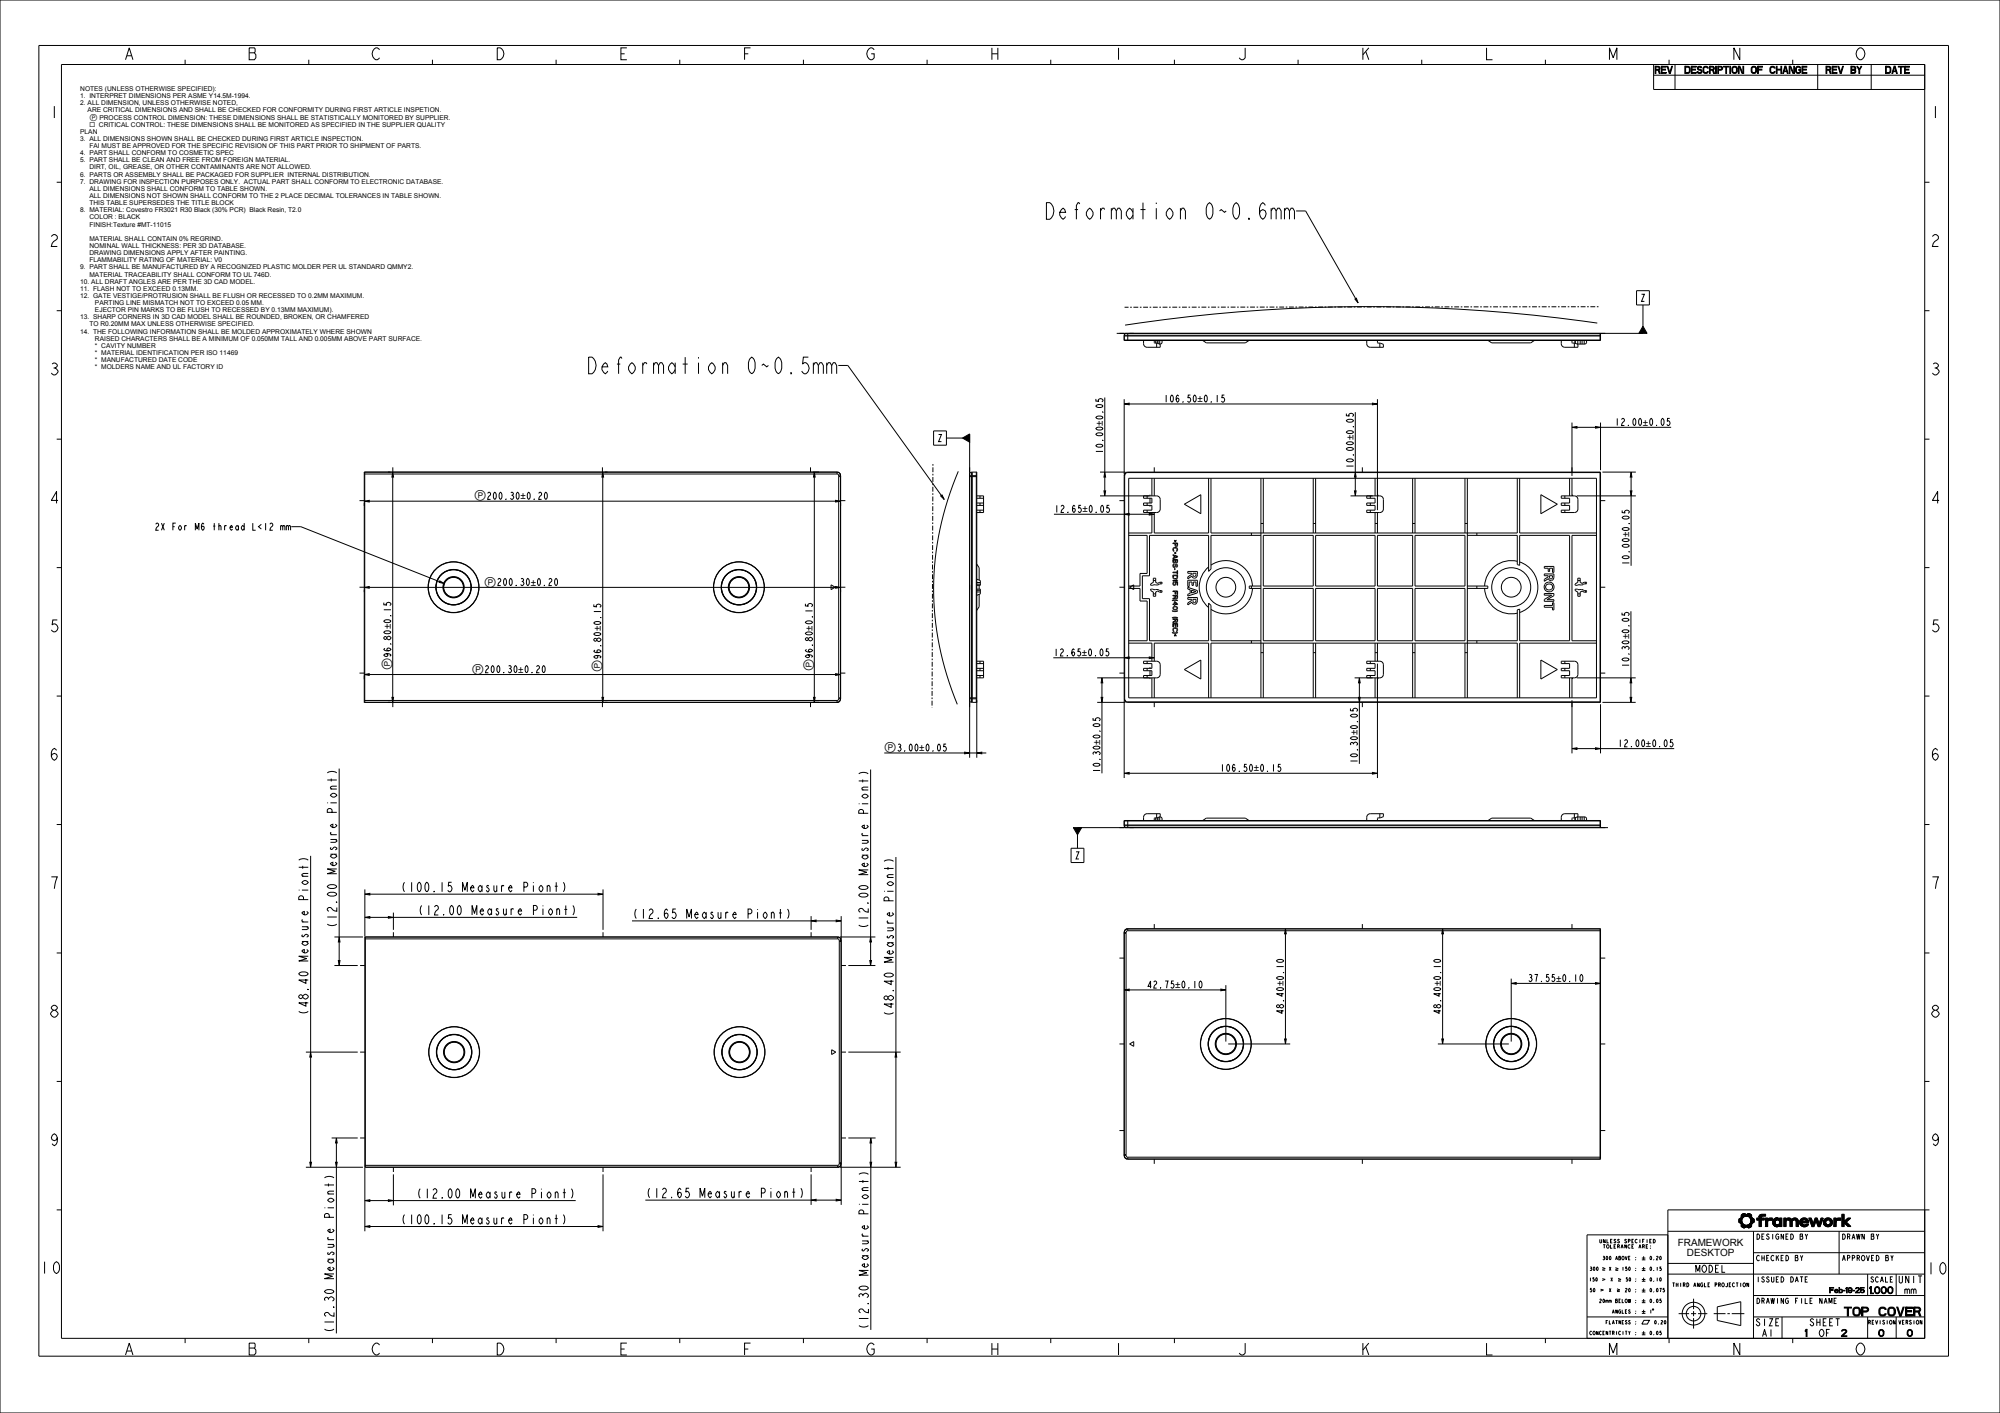
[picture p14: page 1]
(12.00 Measure Piont); (100.15 Measure Piont); (48.40 Measure Piont); (12.00 Measure Piont) (100.15 Measure Piont); (12.65 Measure Piont); (12.30 Measure Piont); MODEL; Feb-19-251.000; TOP COVER; SIZE; SHEET; REVISION; VERSION; REV; DESCRIPTION OF CHANGE; DATE; UNLESS SPECIFIED TOLERANCE ARE:; 300 ABOVE :; 20mm BELOW :; ANGLES :; FLATNESS :; CONCENTRICITY :; 2X For M6 thread; Deformation 0~0.5mm; Deformation 0~0.6mm

NOTES (UNLESS OTHERWISE SPECIFIED):
1. INTERPRET DIMENSIONS PER ASME Y14.5M-1994.
2. ALL DIMENSION, UNLESS OTHERWISE NOTED,
ARE CRITICAL DIMENSIONS AND SHALL BE CHECKED FOR CONFORMITY DURING FIRST ARTICLE INSPETION.
Ⓟ PROCESS CONTROL DIMENSION: THESE DIMENSIONS SHALL BE STATISTICALLY MONITORED BY SUPPLIER.
□ CRITICAL CONTROL: THESE DIMENSIONS SHALL BE MONITORED AS SPECIFIED IN THE SUPPLIER QUALITY
PLAN
3. ALL DIMENSIONS SHOWN SHALL BE CHECKED DURING FIRST ARTICLE INSPECTION.
FAI MUST BE APPROVED FOR THE SPECIFIC REVISION OF THIS PART PRIOR TO SHIPMENT OF PARTS.
4. PART SHALL CONFORM TO COSMETIC SPEC
5. PART SHALL BE CLEAN AND FREE FROM FOREIGN MATERIAL.
DIRT, OIL, GREASE, OR OTHER CONTAMINANTS ARE NOT ALLOWED.
6. PARTS OR ASSEMBLY SHALL BE PACKAGED FOR SUPPLIER INTERNAL DISTRIBUTION.
7. DRAWING FOR INSPECTION PURPOSES ONLY. ACTUAL PART SHALL CONFORM TO ELECTRONIC DATABASE.
ALL DIMENSIONS SHALL CONFORM TO TABLE SHOWN.
ALL DIMENSIONS NOT SHOWN SHALL CONFORM TO THE 2 PLACE DECIMAL TOLERANCES IN TABLE SHOWN.
THIS TABLE SUPERSEDES THE TITLE BLOCK
8. MATERIAL: Covestro FR3021 R30 Black (30% PCR) Black Resin, T2.0
COLOR : BLACK
FINISH:Texture #MT-11015
MATERIAL SHALL CONTAIN 0% REGRIND.
NOMINAL WALL THICKNESS: PER 3D DATABASE.
DRAWING DIMENSIONS APPLY AFTER PAINTING.
FLAMMABILITY RATING OF MATERIAL: V0
9. PART SHALL BE MANUFACTURED BY A RECOGNIZED PLASTIC MOLDER PER UL STANDARD QMMY2.
MATERIAL TRACEABILITY SHALL CONFORM TO UL 746D.
10. ALL DRAFT ANGLES ARE PER THE 3D CAD MODEL.
11. FLASH NOT TO EXCEED 0.13MM.
12. GATE VESTIGE/PROTRUSION SHALL BE FLUSH OR RECESSED TO 0.2MM MAXIMUM.
PARTING LINE MISMATCH NOT TO EXCEED 0.05 MM.
EJECTOR PIN MARKS TO BE FLUSH TO RECESSED BY 0.13MM MAXIMUM).
13. SHARP CORNERS IN 3D CAD MODEL SHALL BE ROUNDED, BROKEN, OR CHAMFERED
TO R0.20MM MAX UNLESS OTHERWISE SPECIFIED.
14. THE FOLLOWING INFORMATION SHALL BE MOLDED APPROXIMATELY WHERE SHOWN
RAISED CHARACTERS SHALL BE A MINIMUM OF 0.050MM TALL AND 0.005MM ABOVE PART SURFACE.
* CAVITY NUMBER
* MATERIAL IDENTIFICATION PER ISO 11469
* MANUFACTURED DATE CODE

* MOLDERS NAME AND UL FACTORY ID

(12.00 Measure Piont) (12.30 Measure Piont)

FRAMEWORK DESKTOP | DESIGNED BY | DRAWN BY

CHECKED BY | APPROVED BY

THIRD ANGLE PROJECTION | | ISSUED DATE | SCALE | UNIT

DRAWING FILE NAME

2

1

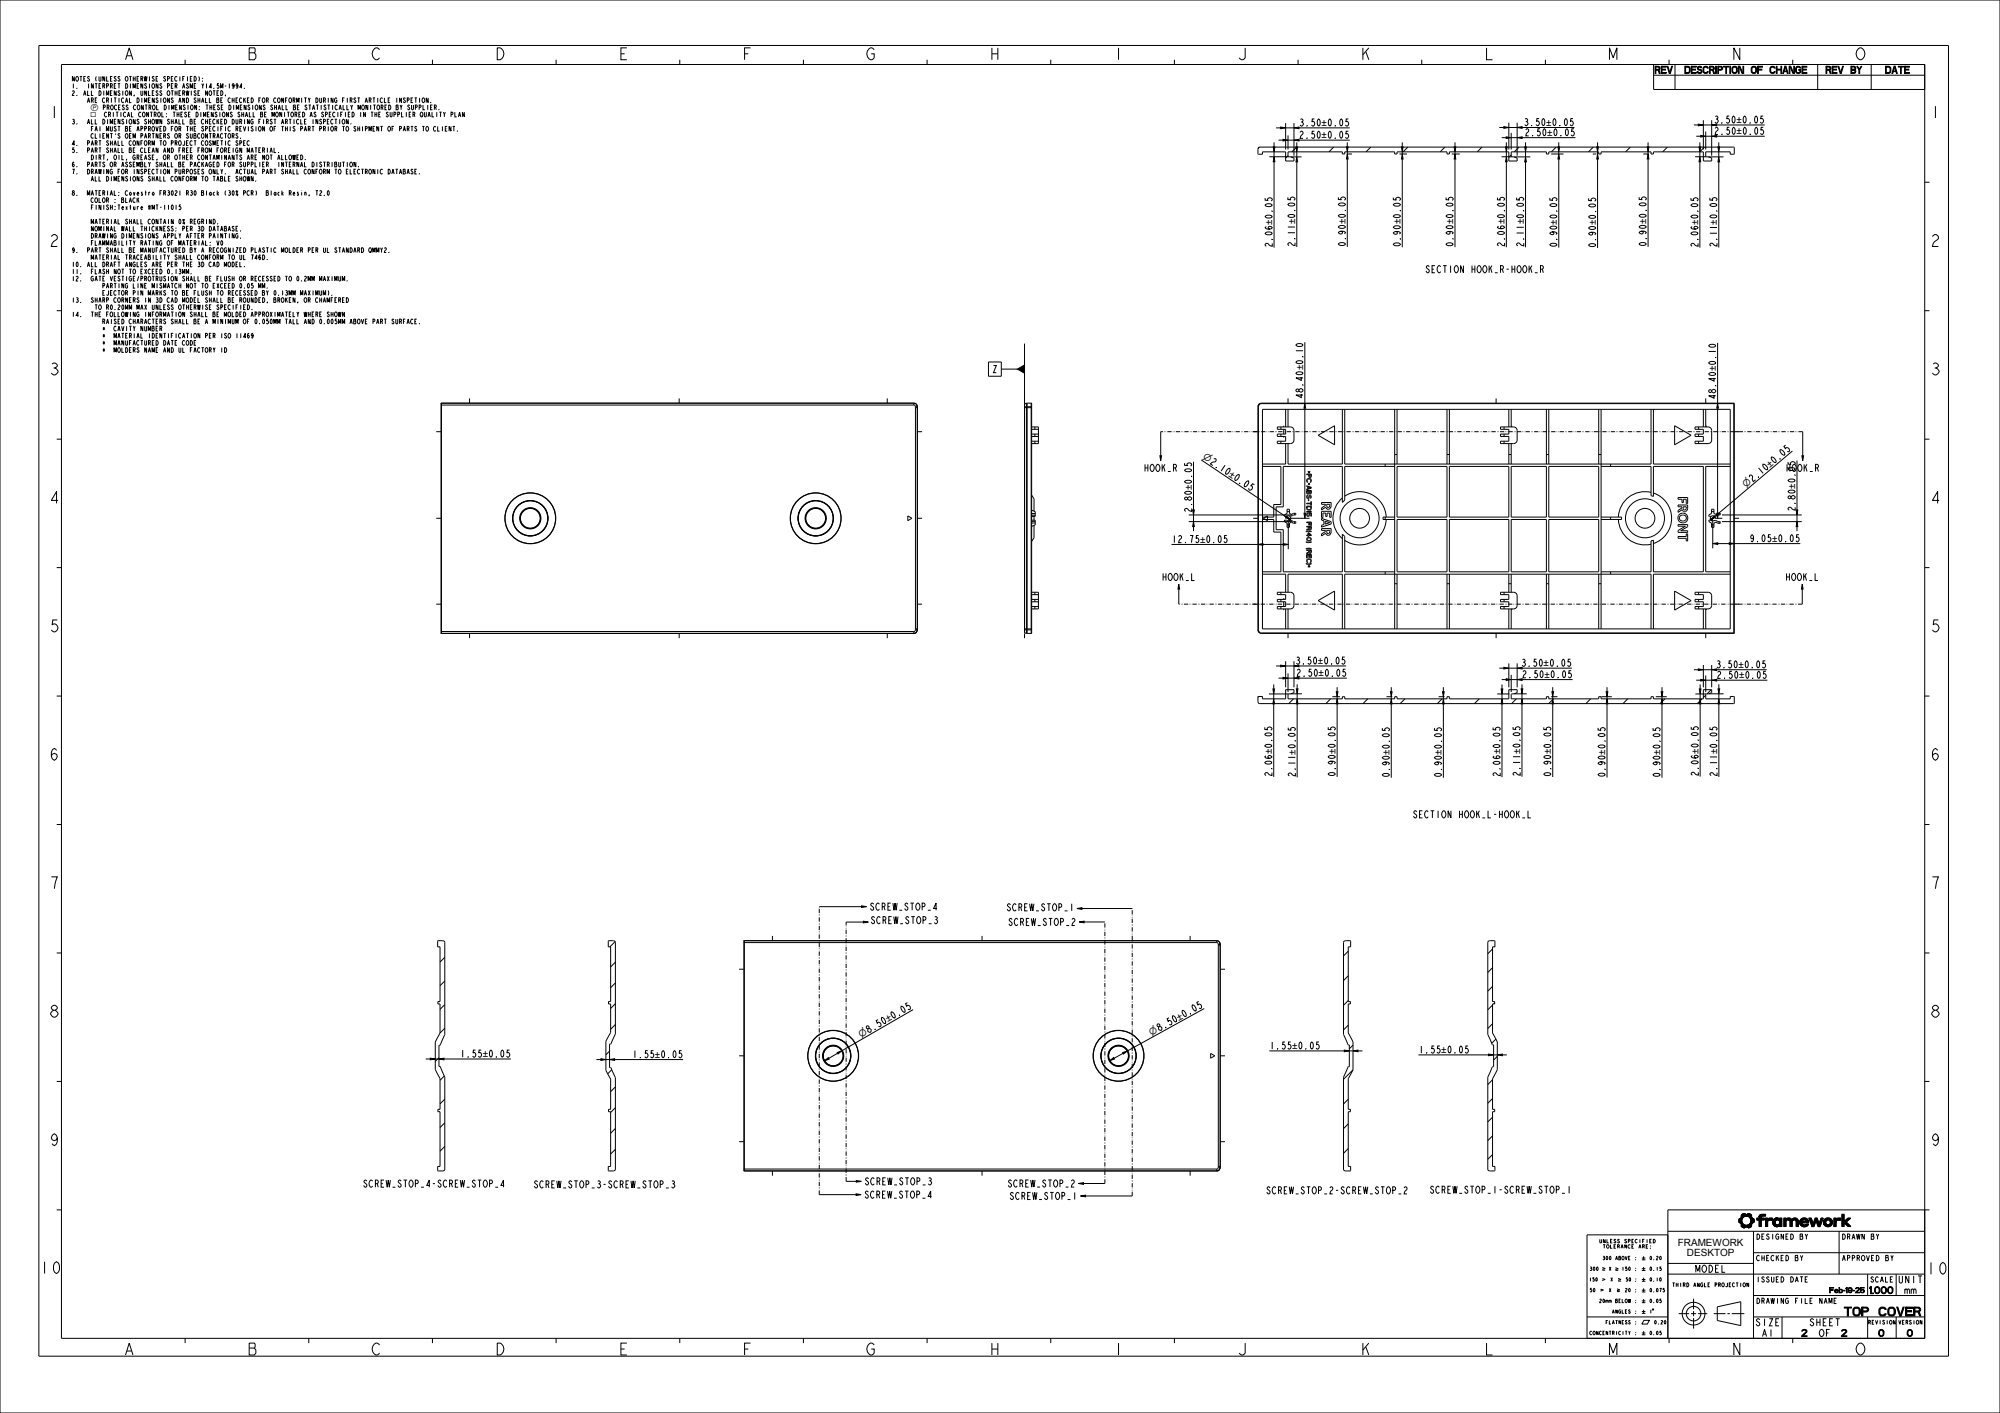
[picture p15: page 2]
MODEL; Feb-19-251.000; TOP COVER; SIZE; SHEET; REVISION; VERSION; REV; DESCRIPTION OF CHANGE; DATE; UNLESS SPECIFIED TOLERANCE ARE:; 300 ABOVE :; 20mm BELOW :; ANGLES :; FLATNESS :; CONCENTRICITY :; NOTES (UNLESS OTHERWISE; SPECIFIED):; 1. INTERPRET; DIMENSIONS PER ASME; 2. ALL; DIMENSION, UNLESS OTHERWISE; NOTED,; ARE; CRITICAL; DIMENSIONS AND SHALL; CHECKED; FOR CONFORMITY; DURING FIRST; ARTICLE; INSPETION.; Ⓟ PROCESS CONTROL; DIMENSION: THESE; DIMENSIONS SHALL; STATISTICALLY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

CLIENT'S OEM PARTNERS OR SUBCONTRACTORS.
COLOR : BLACK
FINISH:Texture #MT-11015

DRAWING DIMENSIONS APPLY AFTER PAINTING.
* CAVITY NUMBER

FRAMEWORK DESKTOP | DESIGNED BY | DRAWN BY

CHECKED BY | APPROVED BY

THIRD ANGLE PROJECTION | | ISSUED DATE | SCALE | UNIT

DRAWING FILE NAME

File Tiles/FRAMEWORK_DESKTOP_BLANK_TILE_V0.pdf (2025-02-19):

A

1

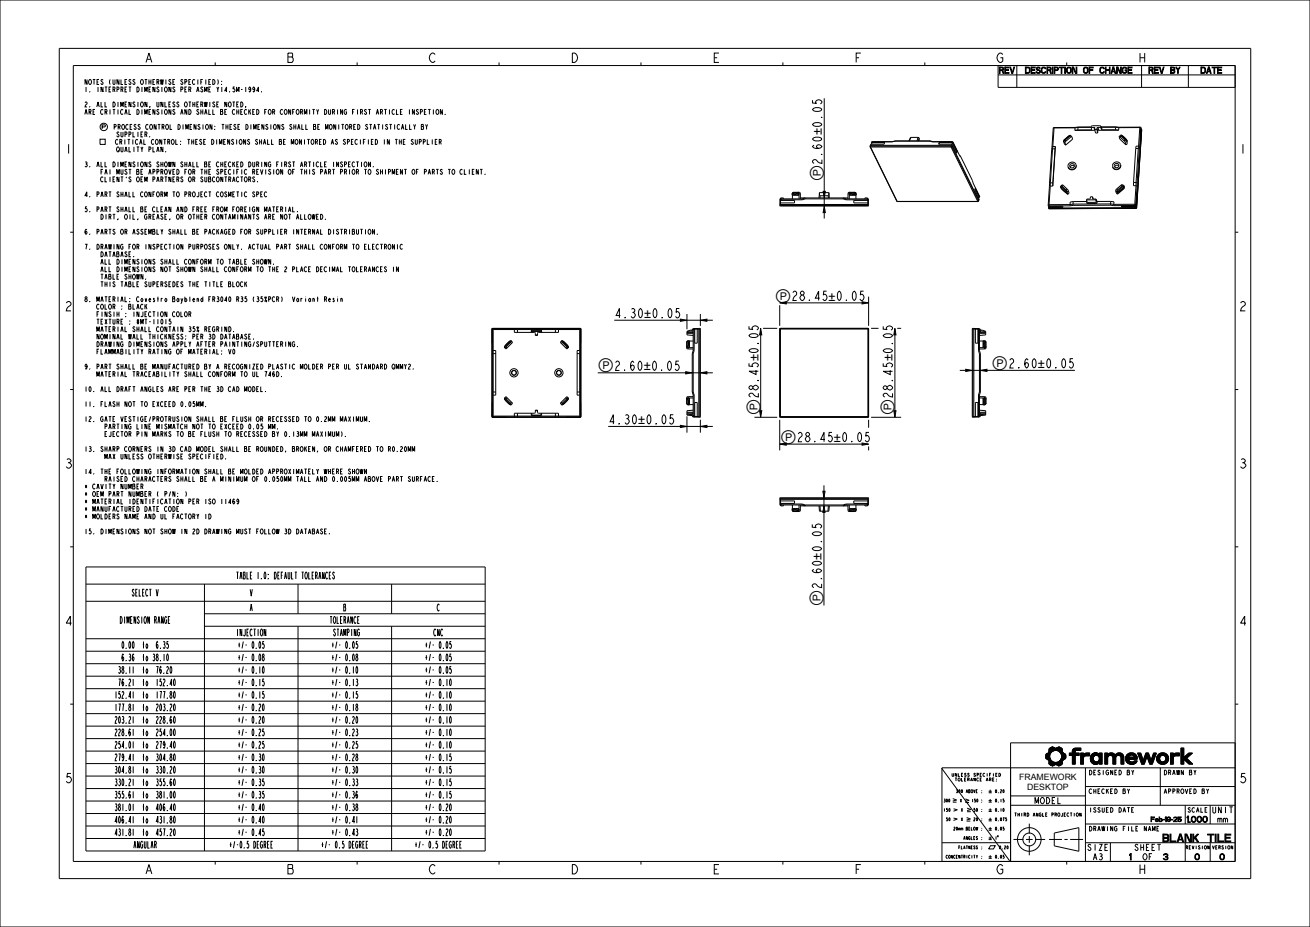
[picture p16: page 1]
REV; DESCRIPTION OF CHANGE; DATE; MODEL; THIRD ANGLE PROJECTION; ISSUED DATE; SCALE; UNIT; DRAWING FILE; NAME; BLANK; TILE SIZE; SHEET; REVISION; VERSION; FLATNESS :; CONCENTRICITY :; NOTES (UNLESS OTHERWISE; SPECIFIED):; 1. INTERPRET; DIMENSIONS PER ASME; 2. ALL; DIMENSION, UNLESS OTHERWISE; NOTED,; ARE; CRITICAL; DIMENSIONS AND SHALL; CHECKED FOR CONFORMITY; DURING FIRST; ARTICLE; INSPETION.; PROCESS CONTROL; DIMENSION: THESE; DIMENSIONS SHALL; MONITORED; STATISTICALLY BY; CONTROL: THESE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

SUPPLIER.
QUALITY PLAN.
CLIENT'S OEM PARTNERS OR SUBCONTRACTORS.
DATABASE.
COLOR : BLACK
DRAWING DIMENSIONS APPLY AFTER PAINTING/SPUTTERING.
* CAVITY NUMBER

TABLE 1.0: DEFAULT TOLERANCES

SELECT V | | V

INJECTION | | STAMPING | | CNC

TOLERANCE

UNLESS SPECIFIED TOLERANCE ARE: 300 ABOVE : 0.20 300 X 150 : 0.15 150 X 50 : 0.10 50 X 20 : 0.075 20mm BELOW : 0.05 ANGLES : 1 | FRAMEWORK DESKTOP | DESIGNED BY | DRAWN BY

CHECKED BY | APPROVED BY

Feb-19-251.000 mm

1

1

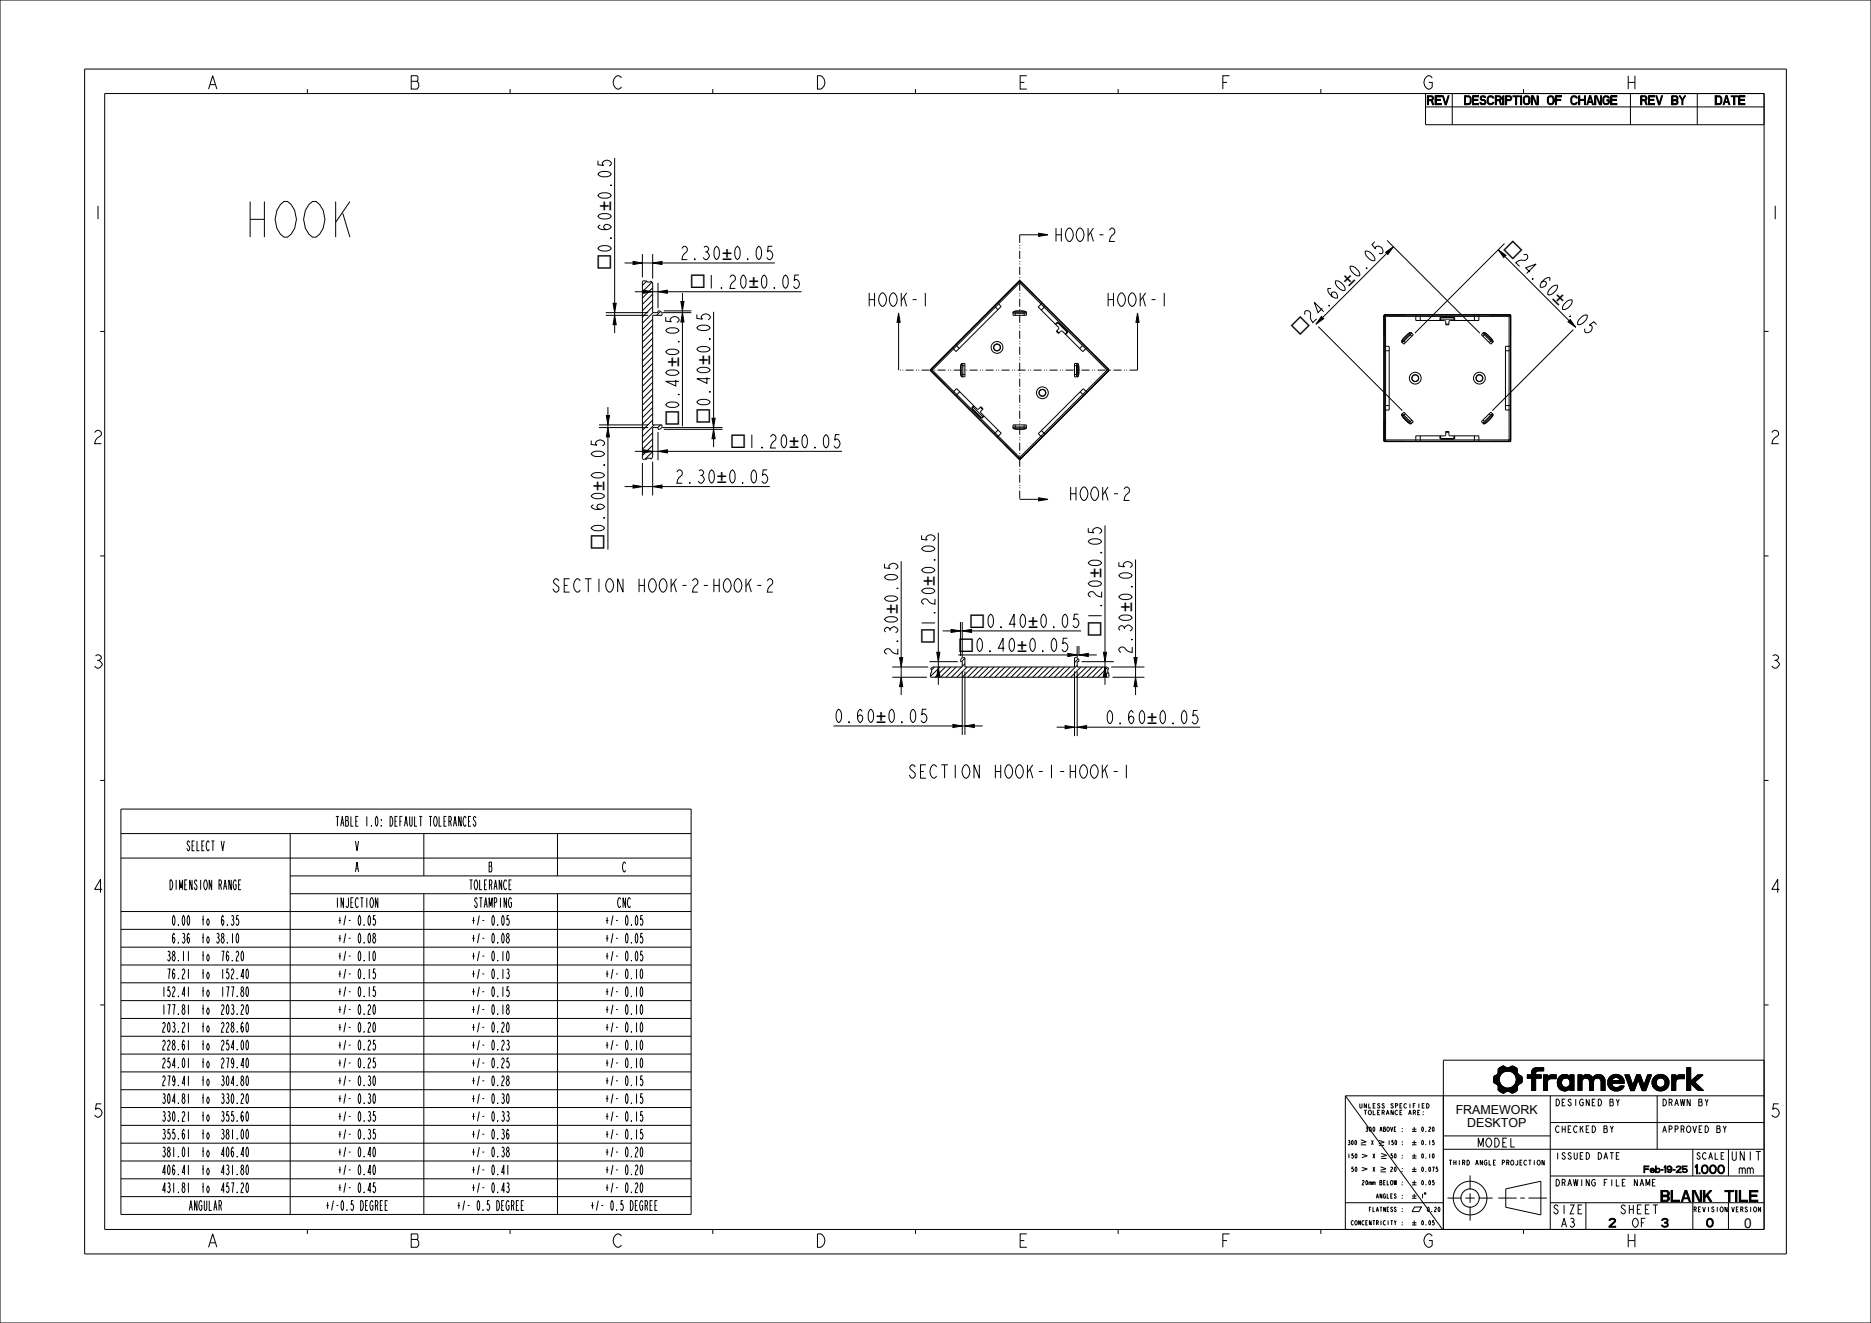
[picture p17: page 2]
MODEL; THIRD ANGLE PROJECTION; ISSUED DATE; SCALE; UNIT; DRAWING FILE; NAME; BLANK; TILE SIZE; SHEET; REVISION; VERSION; HOOK; ANGULAR; +/-0.5 DEGREE; +/- 0.5 DEGREE; DIMENSION RANGE; SECTION; HOOK-1-HOOK-1; HOOK-2-HOOK-2

TABLE 1.0: DEFAULT TOLERANCES

SELECT V | | V

INJECTION | | STAMPING | | CNC

TOLERANCE

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

CHECKED BY | APPROVED BY

Feb-19-251.000 mm

1

1

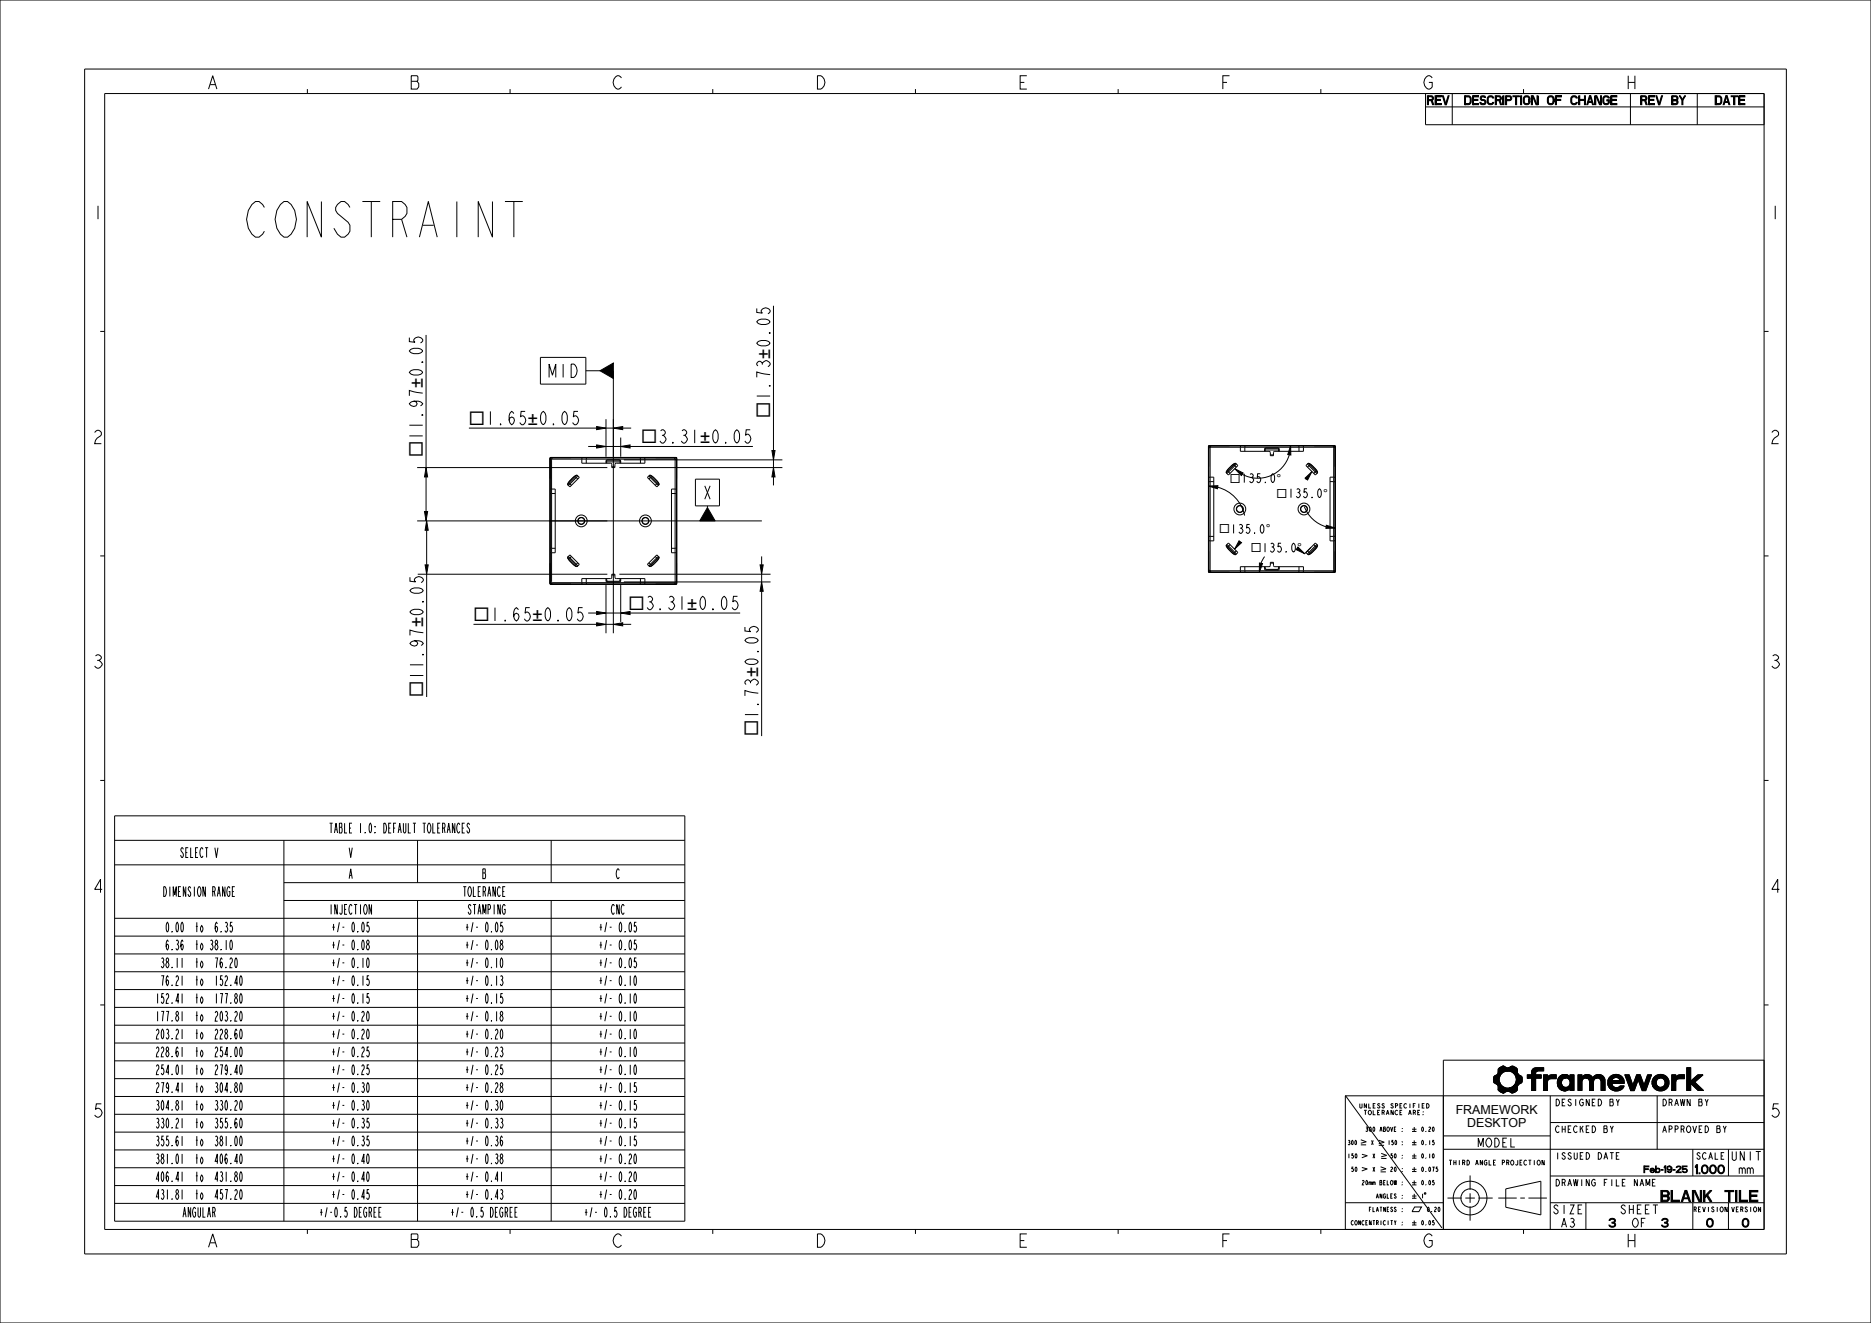
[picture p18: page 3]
MODEL; THIRD ANGLE PROJECTION; ISSUED DATE; SCALE; UNIT; DRAWING FILE; NAME; BLANK; TILE SIZE; SHEET; REVISION; VERSION; CONSTRAINT; MID; ANGULAR; +/-0.5 DEGREE; +/- 0.5 DEGREE; DIMENSION RANGE

TABLE 1.0: DEFAULT TOLERANCES

SELECT V | | V

INJECTION | | STAMPING | | CNC

TOLERANCE

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

CHECKED BY | APPROVED BY

Feb-19-251.000 mm

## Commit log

2025-02-19 Initial CAD and README
    Tiles and Top Cover
    [FRAMEWORK_DESKTOP_BLANK_TILE.stp, FRAMEWORK_DESKTOP_TOP_COVER_V0.stp, framework_desktop_blank_tile_v0_1.dxf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]
2025-02-20 Add handle and top cover CAD
    [handle.scad, handle.stl]
2025-02-20 Add Mainboard drawings
    [framework_desktop_main_pcb_v0_2.dxf, framework_desktop_main_pcb_v0_3.dxf, framework_desktop_main_pcb_v0_4.dxf]
2025-02-20 Improve handle usability
    [handle.scad, handle.stl]
2025-08-22 Add front cover design files
    [fw_desktop_front_cover.stl]
2025-08-28 Interfaces schematic
2025-10-09 More detailed 3D CAD of Mainboard
2025-10-15 Add case CAD
2026-07-06 Add PSU duct
    [framework_desktop_psu_duct.stp]
